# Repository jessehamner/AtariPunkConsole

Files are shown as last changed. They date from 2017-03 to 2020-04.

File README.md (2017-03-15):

# Atari Punk Console Implementation
##### *with modifications*

## What's In Here

- EAGLE CAD schematics 
- Detailed LaTeX documentation
- A few interesting EAGLE CAD scripts
    - at least one of which requires a script in another of my GitHub repositories
- a bill of materials for this implementation
- a python script that makes drawing 8-bit characters in EAGLE CAD pretty easy

## Where Things Are

- cad: EAGLE CAD files and the script to export images from the program
- docs: LaTeX documentation, images, and the bash script that uses ImageMagick to modify and improve the native png image exports
- graphics: EAGLE CAD scripts that draw old 8-bit characters as part of the silkscreen layers of the PCB; includes the source csv and the python script used to make the scripts

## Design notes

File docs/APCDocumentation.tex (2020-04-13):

\documentclass[12pt]{article}
\usepackage{tabularx}
\usepackage{xcolor}
\usepackage{graphicx}
\usepackage{rotating}
\usepackage{lscape}
%\usepackage{booktabs}
\usepackage{comment}
\usepackage{listings}
\usepackage{multicol,multirow}
\usepackage[top=1in, bottom=1in, left=1.25in, right=1.0in]{geometry}
\usepackage{hyperref}
\usepackage{longtable}
\usepackage{marvosym}
\usepackage{amsmath, amssymb}

% A few paragraph formatting parameters:
\parskip = 6pt
\parindent = 0.0in

% Set up the 'listings' package:
\lstdefinestyle{custombash}{
 language=bash, 
 columns=fullflexible, 
 breaklines=true, 
 basicstyle=\ttfamily\footnotesize, 
 numbers=left, 
 numbersep=5pt,
 commentstyle=\itshape\color{mygreen},
 keywordstyle=\bfseries\color{blue},
 numberstyle=\tiny\ttfamily\color{black}, 
 stringstyle=\color{brown},
 otherkeywords={DISPLAY, EXPORT, IMAGE, MONOCHROME, RIPUP, SET, COLOR_LAYER},
 frame=single]
}
\lstset{style=custombash}

% Set some parameters for the graphics:
\DeclareGraphicsExtensions{.pdf,.png,.jpg,.jpeg}
\graphicspath{{./}{../}{./images/}}

% The default "BLUE" for the web links isn't much to my liking. 
\definecolor{webblue}{rgb}{0,0,0.75}
\definecolor{mygreen}{rgb}{0,0.6,0}
\definecolor{gray60}{gray}{0.6}

% Some nice, well-worn shortcuts:
\newcommand{\+}{\item}		% easier than typing \item a lot
%\setlength{\parindent}{0in}	% easier than putting \noindent at every paragraph
\newcommand{\bi}{\begin{itemize}}
\newcommand{\ei}{\end{itemize}}
\newcommand{\bd}{\begin{description}}
\newcommand{\ed}{\end{description}}
\newcommand{\be}{\begin{enumerate}}
\newcommand{\ee}{\end{enumerate}}
\newcommand{\rr}{\raggedright}

% some table formatting shortcuts:
\renewcommand{\thefootnote}{\fnsymbol{footnote}}
\newcommand{\sep}{1mm}
\newcommand{\negsep}{-3mm}
\newcommand{\thisscale}{1.6}
\newcommand{\silkscale}{1.0}
\newcommand{\tabitem}{~~\llap{\textbullet}~~}

% Names of the layout graphics files, so nobody has to go looking for them
\newcommand{\colorimagename}{colorlayout.png}
\newcommand{\twolayermonochrome}{whiteboardlayout.png}
\newcommand{\topmonochrome}{toplayout.png}
\newcommand{\bottommonochrome}{bottomlayout.png}
\newcommand{\bottomsilk}{bottomsilk.png}
\newcommand{\topsilk}{topsilk.png}
\newcommand{\boarddimensions}{dimensions.png}

\newcommand{\revision}{1.2}

% A key for optional output, here, the ``how to make the images" section:
\newif\ifkey
\keyfalse
% Uncommenting \keytrue would set the ``key" variable to TRUE:
\keytrue

\begin{document}
\thispagestyle{empty}
\begin{center}
\begin{Huge}
Atari Punk Console\\
\end{Huge}
\bigskip
\begin{Large}
\ifkey
Assembly, Testing, and Designer's Guide\\
\else
Assembly and Testing Guide\\
\fi

\end{Large}
\bigskip
Board version \revision\\
Guide version 1.2\\
Jesse Hamner\\
\vspace{0.2in}

\end{center}

\tableofcontents

\vfill 

\begin{center}
\begin{tabular}{c p{1.0in} c}
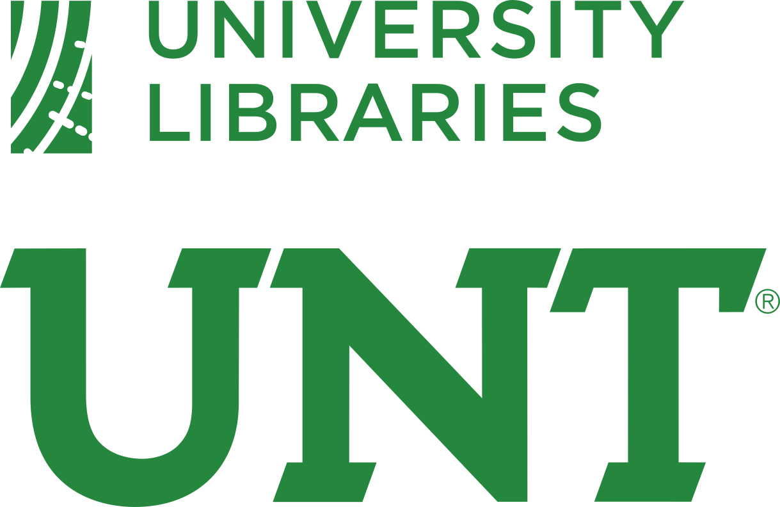
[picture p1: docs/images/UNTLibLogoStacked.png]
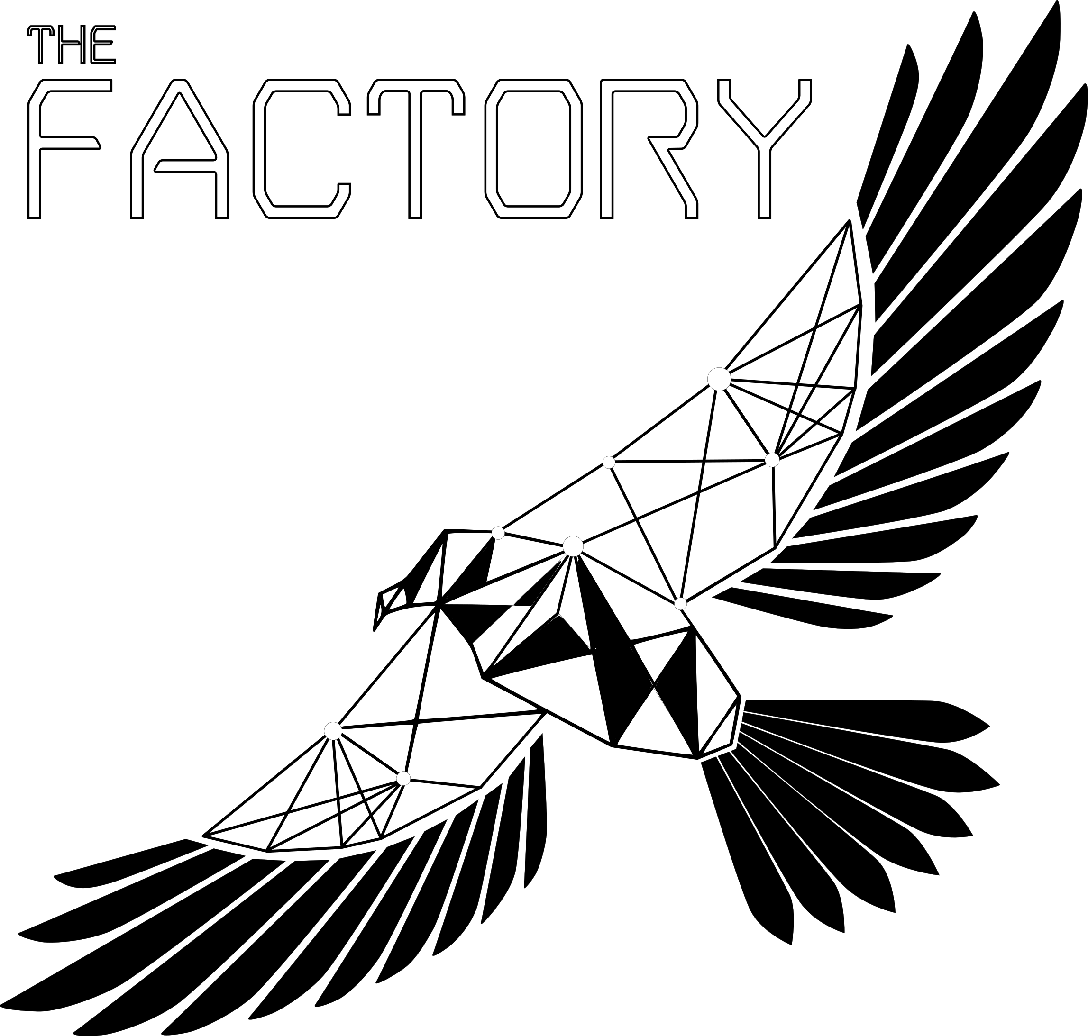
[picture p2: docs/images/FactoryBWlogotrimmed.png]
 & &  \\
\end{tabular}

\emph{Originally developed in collaboration with the UNT Libraries.}
\end{center}

\newpage

\section{Introduction}

In 1983, or some time before that, {\color{webblue}\href{http://www.forrestmims.org}{Forrest Mims III}}, a long-time participant in the electronics, hobbyist, and atmospheric science communities, designed the ``Stepped Tone Generator" using the wildly popular and hugely versatile {\color{webblue}\href{https://en.wikipedia.org/wiki/555_timer_IC}{555 timer integrated circuit}}. He published the design in a Radio Shack (Tandy Corp) book of projects\footnote{Mims, Forrest M., III. 1984. \emph{Engineers's Mini-notebook: 555 Timer IC Projects.} Fort Worth, Texas: Radio Shack.}, and then again in the 1992 \emph{Engineer's Mini-Notebook}\footnote{Mims, Forrest M., III. 1992. \emph{Engineer's Mini-Notebook}. 3\textsuperscript{rd} edition. Fort Worth, Texas: Radio Shack.}.

I was unable to find an example of this board that presented a simple design, an easy soldering task, but also an easy path to customization. People who are getting in to electronics, soldering, and/or ``making" may want a few easy ``wins" for their first few projects, and the ``{\color{webblue}\href{https://en.wikipedia.org/wiki/Atari_Punk_Console}{Atari Punk Console}}", as it has become known, is a simple circuit with a modest amount of expandability. 

I have re-implemented the design with the intent to provide a series of stepping stones from novice to an intermediate ``maker." Maker spaces like UNT's Factory provide a range of tools to end users, but like many tools, learning to use them can be a challenge. Here again, this design of the APC is up to the task. With easy alignment notches and a downloadable reference design for a 3D-printed case, users can learn to solder, solder the APC, and print a case for it, without facing serious hurdles. 

This project and its ancillary pieces allow novices to gain experience in several aspects of hobbyist making, while not facing the full force of electrical or industrial engineering. Put another way: one should not be required to learn typesetting in order to print a Microsoft Word document; neither should one be required to understand G-Code or STL files in order to produce a working and fun electronics project.

This guide provides graphical and instructional information about the assembly of this version of the ``Stepped Tone Generator". Please read this guide all the way through before beginning any work on the boards. 

%%%%%%%%%%%%%%%%%%%

\subsection*{Legal}

This document is intended to assist in the assembly of a circuit board project that synthesizes sound waves. This document comes with ABSOLUTELY NO WARRANTY. This document is released under the Creative Commons Attribution-ShareAlike  (CC BY-SA) license version 4.0. For more, see {\color{webblue}\href{https://creativecommons.org/licenses/}{creativecommons.org}}.
\begin{center}

\end{center}

%%%%%%%%%%%%%%%%%%%

\section{Best Practices}
\bi
\+ Use a wrist-strap ground during soldering; these components can be easily damaged by static electricity
\+ Use thin (perhaps 0.032-inch or 0.8mm) solder for through-hole components
\+ Use a good quality soldering iron
\+ Clean the tip often on the brass scrubber
\+ Re-tin the tip often
\+ Lifting PCB pads and traces is quite possible without much effort---watch the iron temperature, and don't apply heat for more than ten seconds per soldered pin 
\+ Don't buy or use low-quality solder, leaded or not; it gets gummy and is more or less impossible to remove without thermal damage to your components. Use name-brand solder, like {\color{webblue}\href{http://www.kester.com}{Kester}}
\+ Masking tape may be helpful to hold pin headers in place while soldering the underside
\+ Tweezers or small pliers are useful (but not necessary) for placement of the SMD component
\ei

\section{Useful Equipment For Testing}
\bi
\+ A 9V battery
\+ A 6V to 13.8V DC power source, capable of providing at least 300 milliamps of current
\+ A multimeter
\+ A stereo magnifier, an inspection loupe, and/or a USB microscope
\+ A third hand or PCB vise
\+ A set of headphones or a powered speaker
\ei

\section{Assembly Order}

\begin{itemize}
\+ Discrete resistors
\+ Diodes (note the orientation!)
\+ Disc capacitors
\+ Electrolytic (aluminum, polarized) capacitor(s)
\+ 2- and 3-pin headers
\+ LED (note the orientation!)
\+ 8-pin integrated circuit sockets (note the orientation!)
\+ DC power jack
\+ 9V battery cradle
\+ SMD headphone jack (see text)
\+ Variable resistors (potentiometers / rheostats)
\+ Switch
\end{itemize}

After the sockets are installed, consider the orientation of the 555 timers and press them completely into the sockets. It may be helpful to line up four pins on one side with the socket connector, insert them about 1mm, then gently press the opposite side pins inward until they can also be fit into the socket. 

When soldering the stereo jack, heat a large pad on the PCB and melt a little solder onto it. Align the jack and hold it in place (the tab will be on top of the now-tinned PCB pad) with pliers, tweezers, or whatever you have. Hold the soldering iron tip on top of the tab, or touching both the pad and the tab, and the heat will eventually melt the solder and bond the tab to the board. If you have correctly aligned the jack, the other tabs and pads will be easy to solder. If not, re-melt the solder until you can get the jack to align properly. It may be helpful to press down with the tweezers or pliers (even clamping the board and the jack together with them). You don't want the tab to ``float'' up on the solder blob. 

\section{Hardware Testing}

\bi
\+ Turn the switch to `off'
\+ Install a 9V battery in the battery carrier
\+ Using a multimeter, check the voltage at the output (left, on this board) terminal of diodes D1 and D2
\+ Turn the switch to `on' and check the power LED indicator
\+ If the LED does not illuminate, use a multimeter to confirm that there is at least 6 volts available at the LED positive terminal

\+ Set all the knobs to the middle
\+ plug in the headphones and check for sound

\ei

\begin{figure}[ht!]
\begin{center}
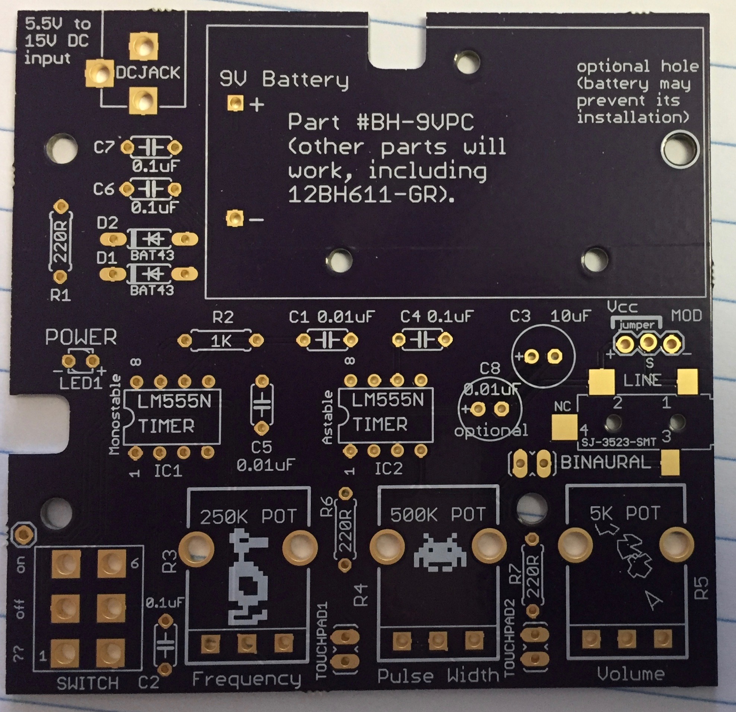
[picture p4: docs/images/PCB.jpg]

\end{center}
\caption{The bare printed circuit board for this project.}
\end{figure}

\begin{figure}[hb!]
\begin{center}
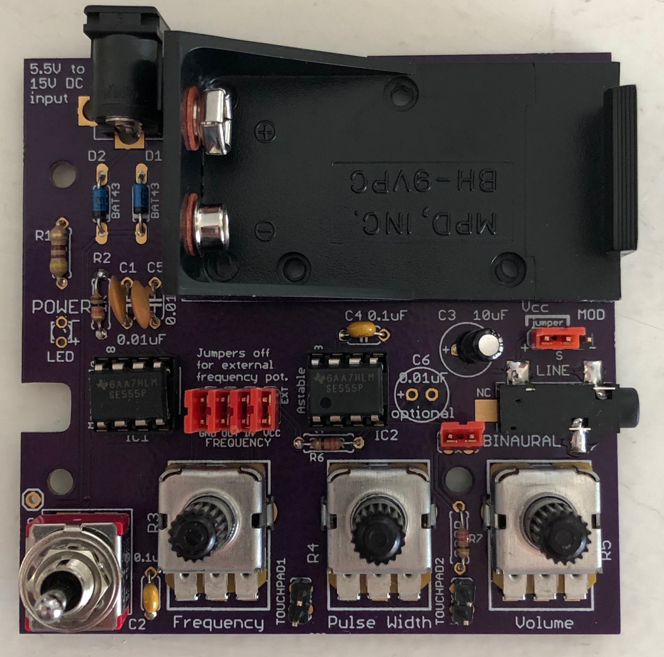
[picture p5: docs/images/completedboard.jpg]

\caption{A completed board, revision 1.2.}
\end{center}
\end{figure}

\clearpage

\section{Board Layout Images}

The next section includes images of the board design and layout for reference during the soldering and testing process. 

\begin{figure}[hb!]
\begin{center}

\end{center}

\caption{Color image unsuitable for monochrome printing. Both layers visible. Red traces are on the top layer, and blue traces are on the bottom layer. As would be expected if the board was transparent, all components on the bottom (although there are none for this board), and text, are reversed.}
\end{figure}

\begin{figure}
\begin{center}



\end{center}

\caption{Both layers visible. As would be expected if you could see through the board, elements on the bottom such as printed text are reversed. For this board, \emph{all components, headers, jacks, and connectors should be mounted on the top layer}, and soldered from the underside.}
\end{figure}

\newpage

\begin{figure}
\begin{center}

\end{center}
\caption{Top layer only. Some larger component outlines are shown in gray, as are two alignment notches in the board.}
\end{figure}

\begin{figure}
\begin{center}

\end{center}
\caption{Bottom layer only. \textbf{Important:} no jacks or headers should be soldered facing ``down." That is, \emph{only pins} should be visible when viewing the board from below. Note the alignment notches are reversed; this perspective is viewed from the bottom, not through the top of the board.}
\end{figure}

\newpage

\begin{figure}
\begin{center}
\begin{tabular}{cc}

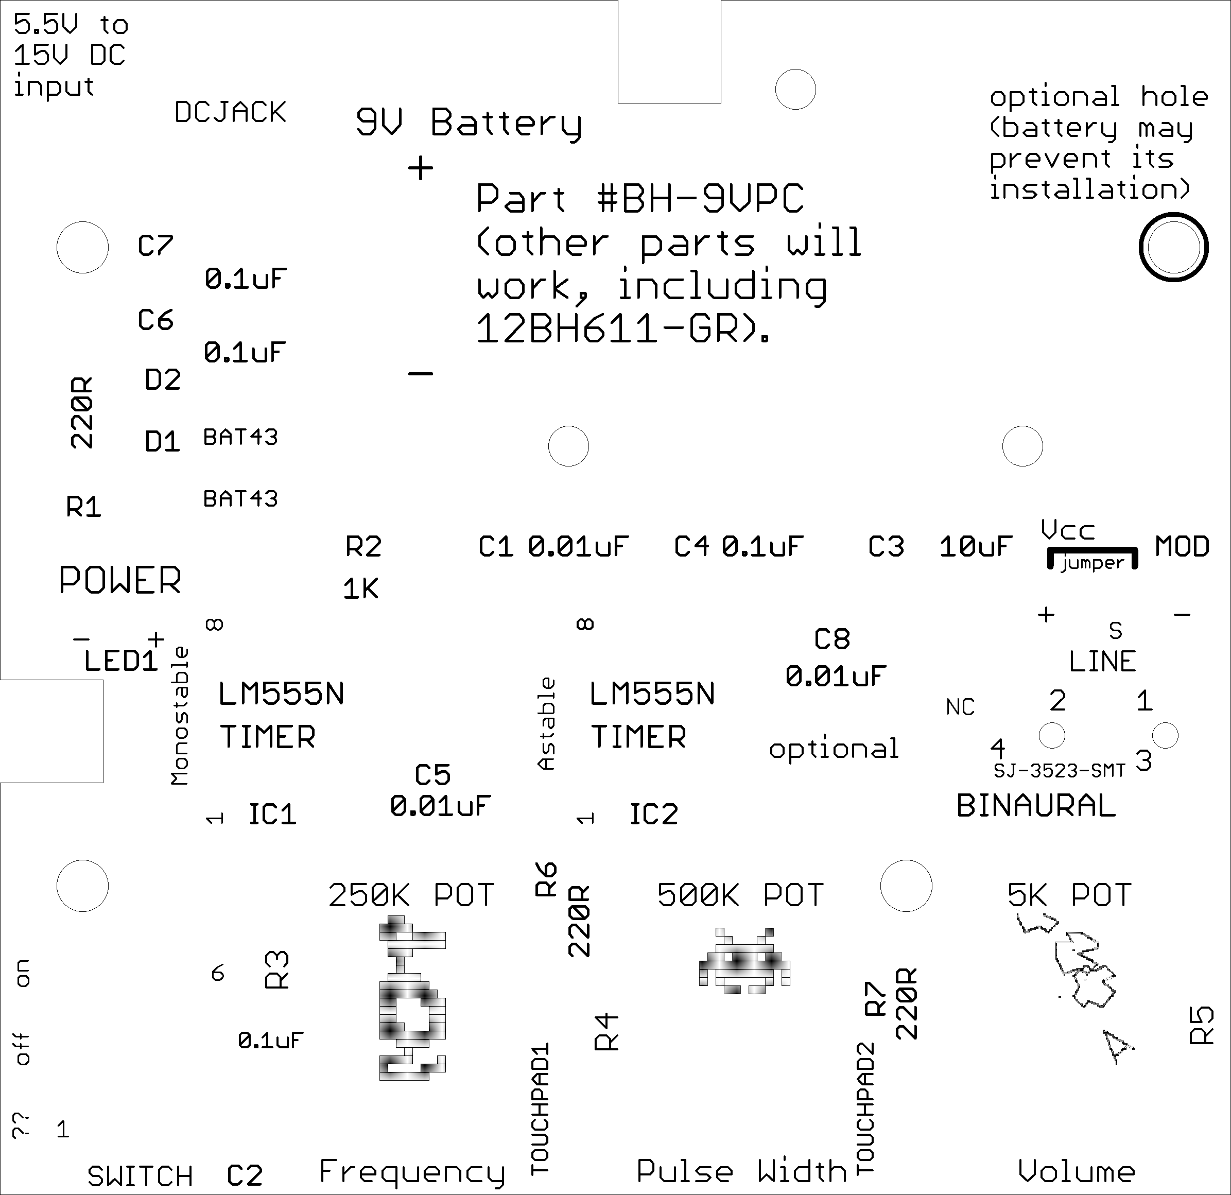
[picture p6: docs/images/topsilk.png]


&

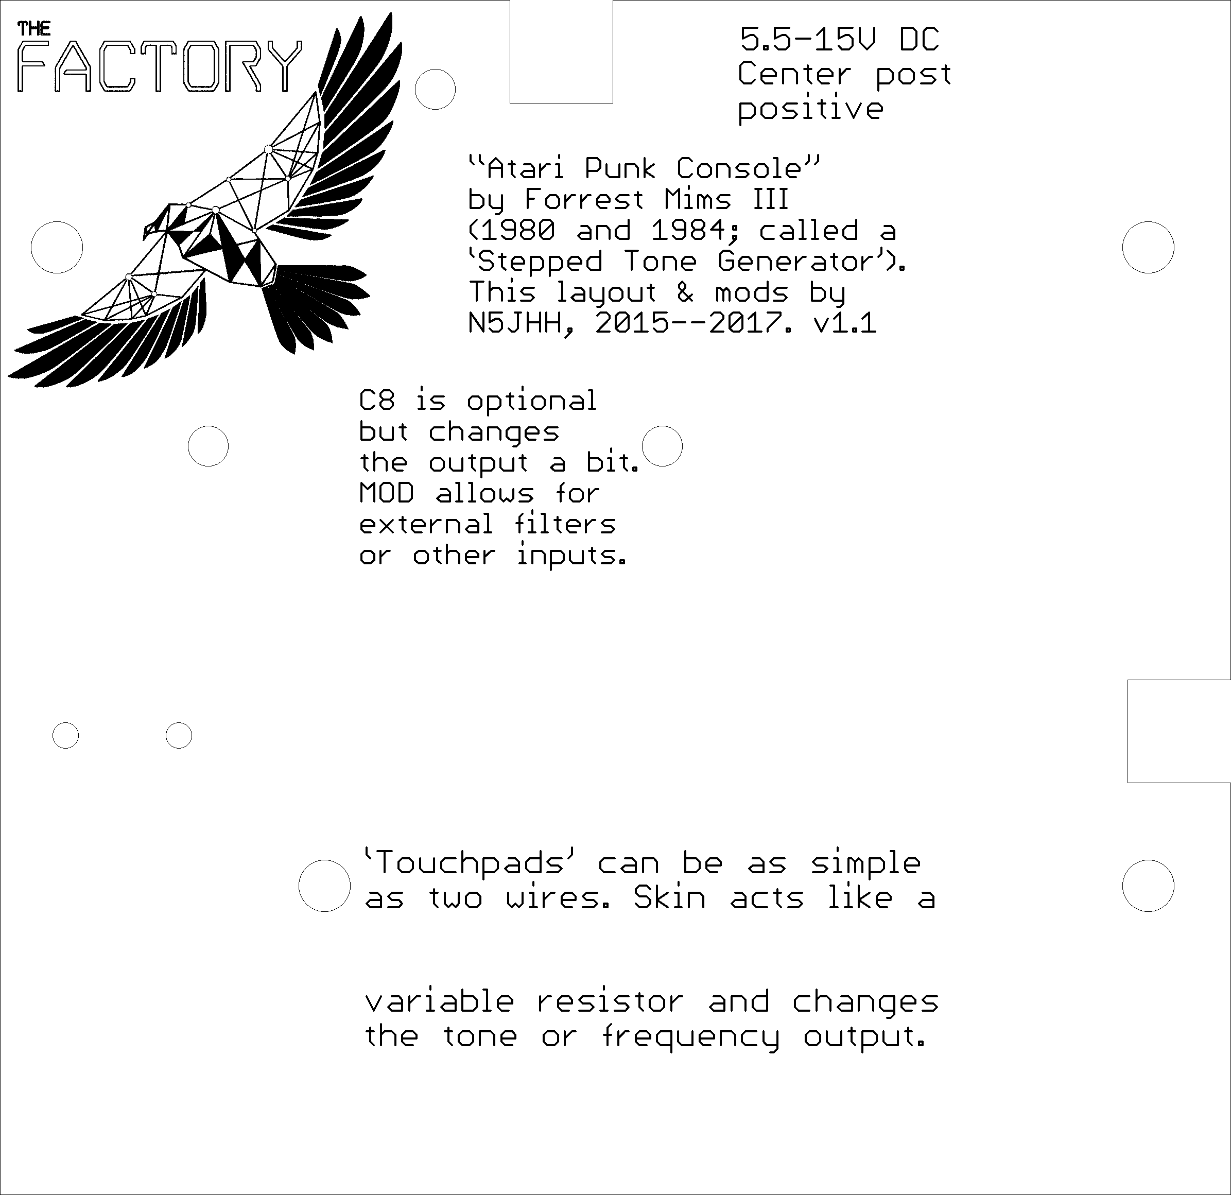
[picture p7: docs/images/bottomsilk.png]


\\

\end{tabular}

\end{center}
\caption{Silkscreens for top and bottom of the board. On the top silkscreen, note that the 8-bit Atari and Taito characters will be hidden under the rotary potentiometers once installed. From left to right: a dragon from the Atari 2600 \emph{Adventure} game; a Taito Space Invader; and a screen from \emph{Asteroids}. On the bottom silkscreen: note optional modification information and the Factory logo, copyright UNT Libraries.}
\end{figure}

\begin{figure}
\begin{center}

\end{center}
\caption{Board dimensions, should you want to design an enclosure for it. The three 2mm holes in the battery cradle could be attached to the underside of the enclosure with machine screws and nuts, but all fasteners must be flush with top surface of the cradle, meaning the underside of the enclosure would need recessed pockets for the nuts, or else rubberized feet that were taller than the portion of the fasteners that protrude through the bottom of the enclosure. It is also possible to create standoffs \emph{within} the case that provide underside clearance for fasteners such that the fasteners do not have exposed surfaces outside the case, at the slight expense of a taller overall case.}
\end{figure}

\clearpage 
\section{Device Schematic}

Although not required to successfully assemble and use the Stepped Tone Generator, some may find the schematic useful or interesting. There are also many schematics of similar implementations of Forrest Mims's work online. This implementation stays very close to the original, with a few small additions like the touchpad headers and the optional capacitors, that can be ignored if desired. I varied a few of the other components based on experience. To create this image, from the schematic pane, type (no quotes!)

\verb|EXPORT IMAGE $HOME/some/useful/path/APCschematic.png 800|

\bigskip

\begin{figure}[hb!]
\begin{center}
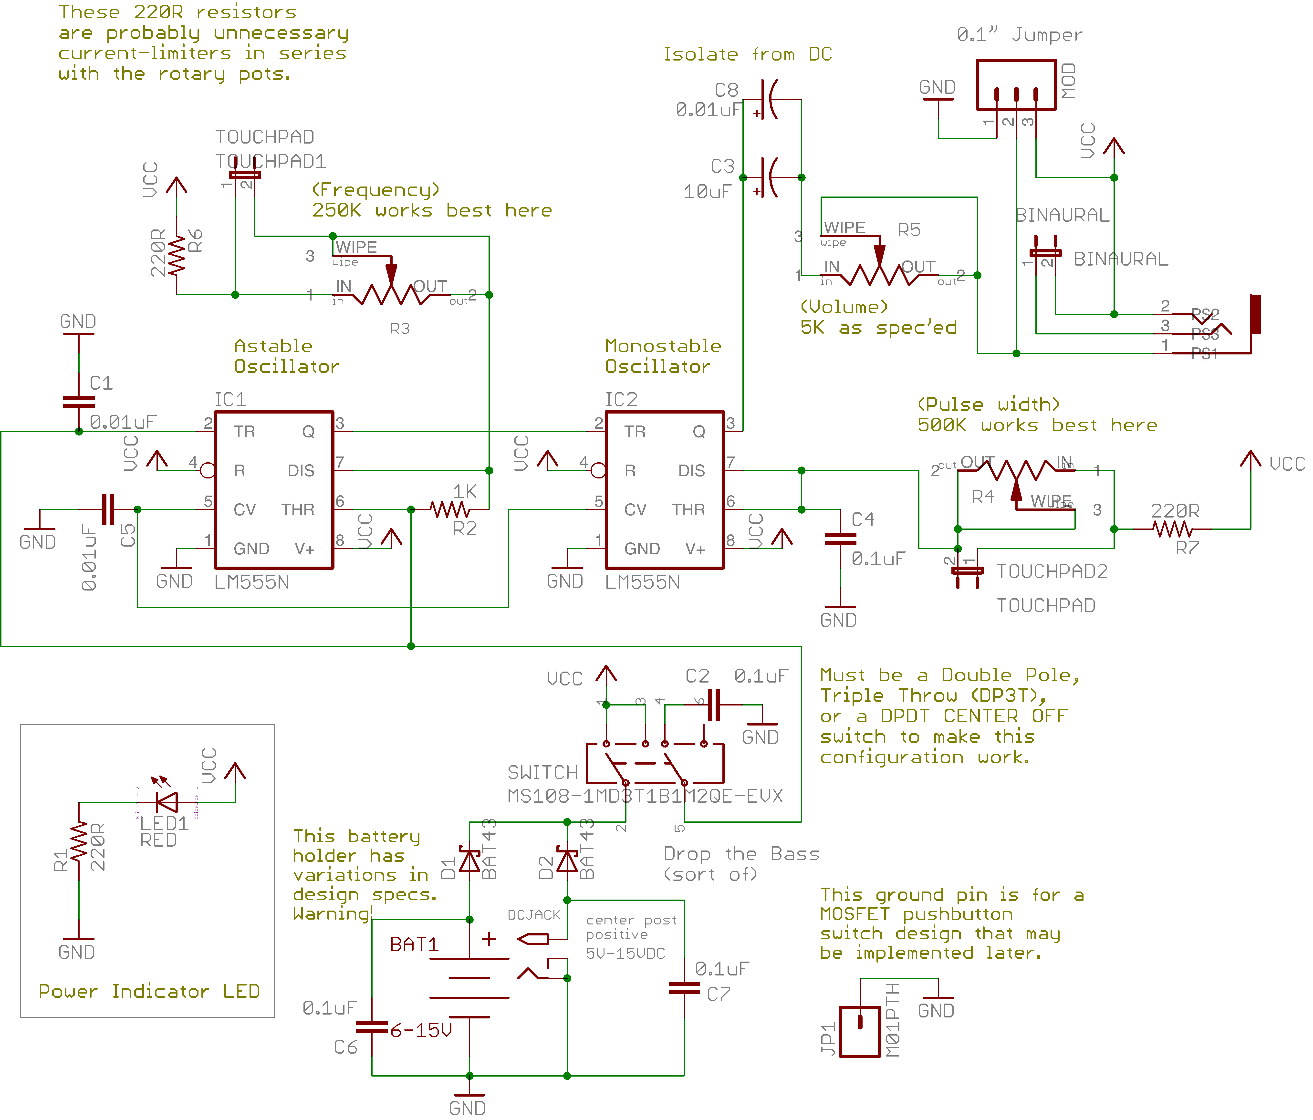
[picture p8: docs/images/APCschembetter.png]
 % original file: APCschematic.png
\end{center}
\caption{Schematic, with notes, as implemented in the board for this version.}
\end{figure}

%%%%%%%%%%%%%%%%%%%%%%%%%%%%%%%%%%%%%%%%%%%%%%%%%%%%%%%%%%%%%
%
% Optional section on making the images:
%
%%%%%%%%%%%%%%%%%%%%%%%%%%%%%%%%%%%%%%%%%%%%%%%%%%%%%%%%%%%%%

\ifkey 

\clearpage
\section{How To Make The Images In This Document}

This document includes images created from within Eagle CAD and using external programs. To show how it is done, and to provide any hints to those who would like to see how the documentation was made, I include the following mini-tutorial.

\subsection*{EagleCAD Schematic and Layout Images }

An EagleCAD script is provided in Figure \ref{fig:codelistexport} and in the GitHub repository. Run the script from within EagleCAD and the first set of images will appear. Basically, the script turns on the layers for each particular image, sets color or monochrome, sets the resolution to 600 DPI, and exports each resulting layer set to a PNG file. For instance, before making the \emph{top} layer, the script turns off the set of layers in EagleCAD that would make it hard to parse the top components -- i.e.~all of the ``bottom'' layers, like 16, 22, 24, 26, 28, 30, 32, 34, 36, 40, 42, 52, 122, 126, 128, and, as noted above, 200 (where the logo image silkscreen resides). To make an image of the underside, a similar operation is performed, blanking the ``top" layers. The script writes image files called:

\bigskip

\begin{tabular}{lll}
\tabitem \texttt{fullcolorboard.png} && \tabitem \texttt{boardlayout.png} \\[\sep]
\tabitem \texttt{boardtoplayout.png} && \tabitem \texttt{boardbottomlayout.png} \\[\sep]
\tabitem \texttt{boardbottomsilk.png} && \tabitem \texttt{boardtopsilk.png} \\[\sep]
\tabitem \texttt{boarddimensions.png} \\[\sep]
\end{tabular}

\begin{figure}
\vspace{-0.5in}
% Code listing:
\lstinputlisting[
 language=bash, 
 columns=fullflexible, 
 breaklines=true, 
 basicstyle=\ttfamily\footnotesize, 
 numbers=left, 
 numbersep=5pt,
 commentstyle=\color{mygreen},
 numberstyle=\tiny\ttfamily\color{black}, 
 frame=single]
 {./exportspecificlayers.scr}

\caption{The \texttt{EagleCAD} script to export images from EagleCAD.}
\label{fig:codelistexport}
\end{figure}

The script to appropriately convert the images is seen in Figure \ref{fig:codelistconvert}. The resulting files are called: 

\medskip

\begin{tabular}{lll}
\tabitem \texttt{\colorimagename} && \tabitem \texttt{\twolayermonochrome} \\[\sep]
\tabitem \texttt{\topmonochrome} && \tabitem \texttt{\bottommonochrome} \\[\sep]
\tabitem \texttt{\topsilk} && \tabitem \texttt{\bottomsilk} \\[\sep]
\tabitem \texttt{\boarddimensions} \\[\sep]
\end{tabular}
\medskip

\noindent This script was written for macOS but should run on any system with 
{\color{webblue}\href{https://en.wikipedia.org/wiki/Bash_%28Unix_shell%29}{\texttt{bash}}}
and {\color{webblue}\href{http://www.imagemagick.org/script/index.php}{ImageMagick}} installed.

\newpage

\begin{figure}[ht!]
\vspace{-0.5in}
% Code listing:
\lstinputlisting[
 language=bash, 
 columns=fullflexible, 
 breaklines=true, 
 basicstyle=\ttfamily\footnotesize, 
 numbers=left, 
 numbersep=5pt,
 commentstyle=\color{mygreen},
 numberstyle=\tiny\ttfamily\color{black}, 
 frame=single]
 {./images/imageprep.sh}
\caption{The \texttt{bash} script to correctly color the exported images from EagleCAD.}
\label{fig:codelistconvert}

\end{figure}

\clearpage
\newpage

\subsection*{8-bit Art in Eagle CAD}

The PCB also includes three pieces of art from the ancient era of video games. The Asteroids ship was converted using the \texttt{import-bmp.ulp} user language script that is included in Eagle CAD. The other two presented a fun challenge, which was to draw the 8-bit sprites using the Eagle CAD scripting language. It's pretty easy to draw squares and rectangles using the language, so I wrote a Python script that reads in a very simple csv file, composed of rows of comma-separated ``1'' or ``0'' cells. The Python script then writes out a nice (and easily scalable, if you check out the top of the script) Eagle CAD script that draws the figure in the layer you specify. It's much faster than drawing it yourself, and the CAM script runs much faster too, since the sprites are so simple.

\medskip

\begin{figure}[h!]

\begin{tabular}{ m{2.7in}  m{3.0in} }
\hline\\[\negsep]
\multicolumn{1}{c}{\textbf{CSV code}} & \multicolumn{1}{c}{\textbf{Image}} \\[\sep]
\hline
\bigskip
\lstinputlisting[
language=bash, 
 columns=fullflexible, 
 breaklines=true, 
 basicstyle=\ttfamily\footnotesize, 
 numbers=left, 
 numbersep=5pt,
 commentstyle=\color{black},
 numberstyle=\tiny\ttfamily\color{black}, 
 frame=none]
 {../graphics/pitfallharry.txt}

&

\fbox{
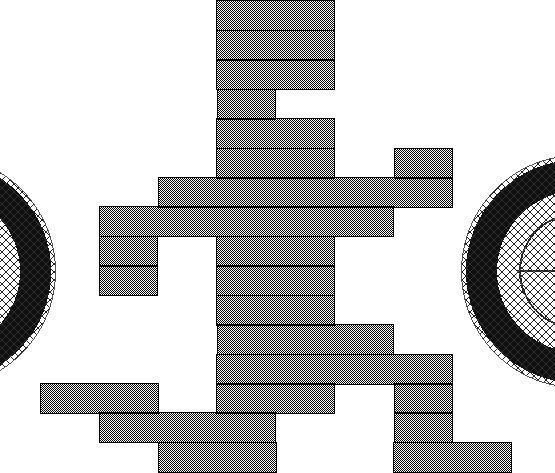
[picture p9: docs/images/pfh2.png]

}
\\
\hline
\end{tabular}

\caption{The comma-separated source text that \texttt{eagledraw.py} uses to write the script to draw Pitfall Harry, and the resulting image in Eagle CAD. Pitfall Harry is not displayed on the the board, but is used here as an example.}
\label{fig:pitfallharry}
\end{figure}

\clearpage
\newpage

\else
	\newpage
\fi

\begin{sidewaystable}
\section*{Bill of Materials}
\input{APC1BOM_export.tex}
\end{sidewaystable}

\clearpage

\section{Change Log}

\bd

\+[Revision \revision{}:] March 2017
\bi
\+ Fixed wiring on two potentiometers (I outsmarted myself and wired them in reverse, so the volume control, e.g., worked backwards)
\+ Re-routed traces to make the design friendly for desktop CNC mills
\+ Added two current-limiting resistors just to use best practices for the rotary potentiometers; the extra 220 Ohms doesn't affect the sound, but prevents runaway current should the wiper fail.
\ei

\+[1.0:] February 2017
\bi
\+ Initial release
\+ Changed switch to one in current production
\+ Re-routed and simplified some traces
\+ Moved and added labels
\+ Moved some discrete components
\ei

\+[0.4:] July 2016
\bi
\+ Shrunk the footprint of discrete resistors
\+ Renumbered a few components
\+ Altered the 9V cradle part's footprint to improve pin placement
\+ Changed a few labels
\ei

\+[0.3:] June 2016
\bi
\+ Changed switch
\+ Moved a few components for clearance
\ei

\+[0.2:] January 2016
\bi
\+ Revealed a problem with the switch layout
\ei

\+[0.1:] December 2015
\bi
\+ Corrected problems with component layout, clearance, and part names
\+ Added board cutouts to ensure it only fits in the enclosure in one specific orientation
\+ Shrunk discrete component pin spacings from 10mm to 7mm
\ei
\ed

\vfill

\begin{center}
\emph{This is the last page.}
\end{center}

\end{document}

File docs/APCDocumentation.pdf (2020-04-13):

# Atari Punk Console

## Assembly, Testing, and Designer’s Guide

Board version 1.2
Guide version 1.2
Jesse Hamner

## Contents

1 Introduction | 2
2 Best Practices | 3
3 Useful Equipment For Testing | 3
4 Assembly Order | 3
5 Hardware Testing | 4
6 Board Layout Images | 6
7 Device Schematic | 11
8 How To Make The Images In This Document | 12
9 Change Log | 17

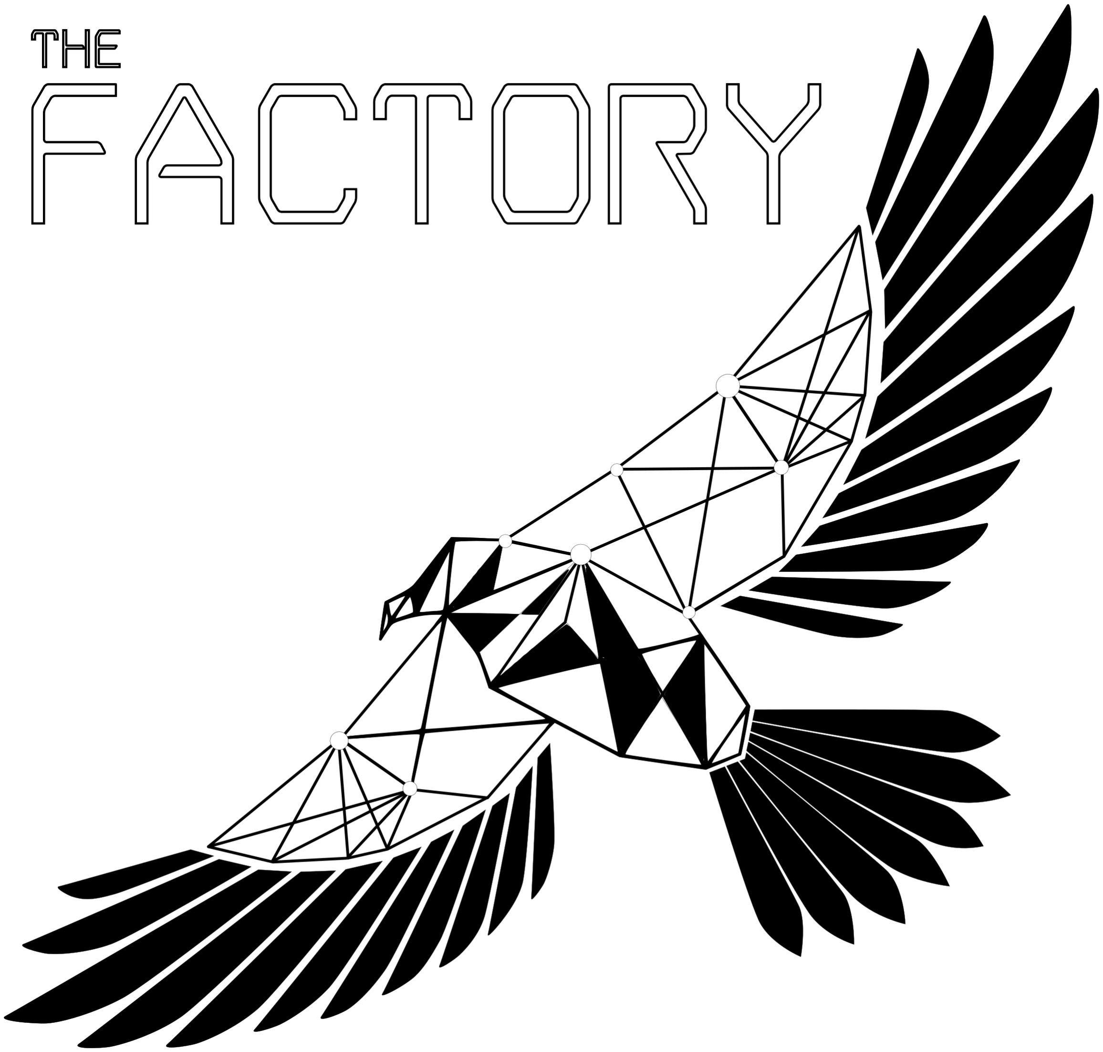
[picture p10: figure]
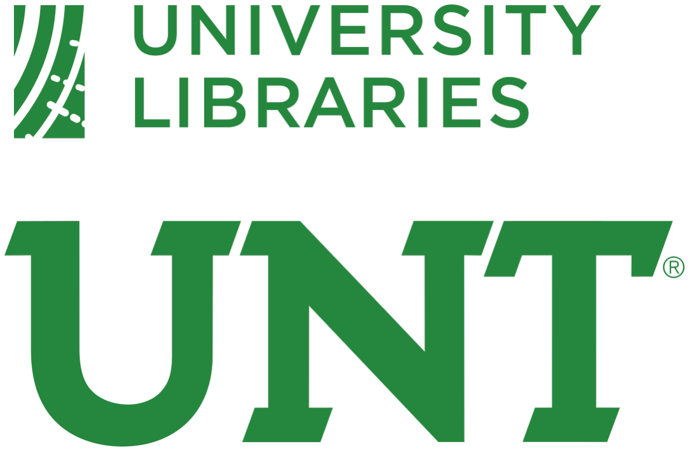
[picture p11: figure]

Originally developed in collaboration with the UNT Libraries.

## 1 Introduction

In 1983, or some time before that, Forrest Mims III, (http://www.forrestmims.org) a long-time participant in the electronics, hobbyist, and atmospheric science communities, designed the “Stepped Tone Generator” using the wildly popular and hugely versatile 555 timer integrated circuit. (https://en.wikipedia.org/wiki/555_timer_IC) He published the design in a Radio Shack (Tandy Corp) book of projects∗
, and then again
in the 1992 Engineer’s Mini-Notebook †

I was unable to find an example of this board that presented a simple design, an easy soldering task, but also an easy path to customization. People who are getting in to electronics, soldering, and/or “making” may want a few easy “wins” for their first few projects, and the “Atari Punk Console”, (https://en.wikipedia.org/wiki/Atari_Punk_Console) as it has become known, is a simple circuit with a modest amount of expandability.

I have re-implemented the design with the intent to provide a series of stepping stones from novice to an intermediate “maker.” Maker spaces like UNT’s Factory provide a range of tools to end users, but like many tools, learning to use them can be a challenge. Here again, this design of the APC is up to the task. With easy alignment notches and a downloadable reference design for a 3D-printed case, users can learn to solder, solder the APC, and print a case for it, without facing serious hurdles.

This project and its ancillary pieces allow novices to gain experience in several aspects of hobbyist making, while not facing the full force of electrical or industrial engineering. Put another way: one should not be required to learn typesetting in order to print a Microsoft Word document; neither should one be required to understand G-Code or STL files in order to produce a working and fun electronics project.

This guide provides graphical and instructional information about the assembly of this version of the “Stepped Tone Generator”. Please read this guide all the way through before beginning any work on the boards.

### Legal

This document is intended to assist in the assembly of a circuit board project that synthesizes sound waves. This document comes with ABSOLUTELY NO WARRANTY. This document is released under the Creative Commons Attribution-ShareAlike (CC BY-SA) license version 4.0. For more, see creativecommons.org. (https://creativecommons.org/licenses/)

∗Mims, Forrest M., III. 1984. Engineers’s Mini-notebook: 555 Timer IC Projects. Fort Worth, Texas: Radio Shack.
†Mims, Forrest M., III. 1992. Engineer’s Mini-Notebook. 3rd edition. Fort Worth, Texas: Radio Shack.

## 2 Best Practices

- Use a wrist-strap ground during soldering; these components can be easily damaged by static electricity
- Use thin (perhaps 0.032-inch or 0.8mm) solder for through-hole components
- Use a good quality soldering iron
- Clean the tip often on the brass scrubber
- Re-tin the tip often
- Lifting PCB pads and traces is quite possible without much effort—watch the iron temperature, and don’t apply heat for more than ten seconds per soldered pin
- Don’t buy or use low-quality solder, leaded or not; it gets gummy and is more or less impossible to remove without thermal damage to your components. Use name-brand solder, like Kester (http://www.kester.com)
- Masking tape may be helpful to hold pin headers in place while soldering the underside
- Tweezers or small pliers are useful (but not necessary) for placement of the SMD component

## 3 Useful Equipment For Testing

- A 9V battery
- A 6V to 13.8V DC power source, capable of providing at least 300 milliamps of current
- A multimeter
- A stereo magnifier, an inspection loupe, and/or a USB microscope
- A third hand or PCB vise
- A set of headphones or a powered speaker

## 4 Assembly Order

- Discrete resistors
- Diodes (note the orientation!)

- Disc capacitors
- Electrolytic (aluminum, polarized) capacitor(s)
- 2- and 3-pin headers
- LED (note the orientation!)
- 8-pin integrated circuit sockets (note the orientation!)
- DC power jack
- 9V battery cradle
- SMD headphone jack (see text)
- Variable resistors (potentiometers / rheostats)
- Switch

After the sockets are installed, consider the orientation of the 555 timers and press them completely into the sockets. It may be helpful to line up four pins on one side with the socket connector, insert them about 1mm, then gently press the opposite side pins inward until they can also be fit into the socket.

When soldering the stereo jack, heat a large pad on the PCB and melt a little solder onto it. Align the jack and hold it in place (the tab will be on top of the now-tinned PCB pad) with pliers, tweezers, or whatever you have. Hold the soldering iron tip on top of the tab, or touching both the pad and the tab, and the heat will eventually melt the solder and bond the tab to the board. If you have correctly aligned the jack, the other tabs and pads will be easy to solder. If not, re-melt the solder until you can get the jack to align properly. It may be helpful to press down with the tweezers or pliers (even clamping the board and the jack together with them). You don’t want the tab to “float” up on the solder blob.

## 5 Hardware Testing

- Turn the switch to ‘off’
- Install a 9V battery in the battery carrier
- Using a multimeter, check the voltage at the output (left, on this board) terminal of diodes D1 and D2
- Turn the switch to ‘on’ and check the power LED indicator
- If the LED does not illuminate, use a multimeter to confirm that there is at least 6 volts available at the LED positive terminal

- Set all the knobs to the middle
- plug in the headphones and check for sound


Figure 1: The bare printed circuit board for this project.


Figure 2: A completed board, revision 1.2.

## 6 Board Layout Images

The next section includes images of the board design and layout for reference during the soldering and testing process.

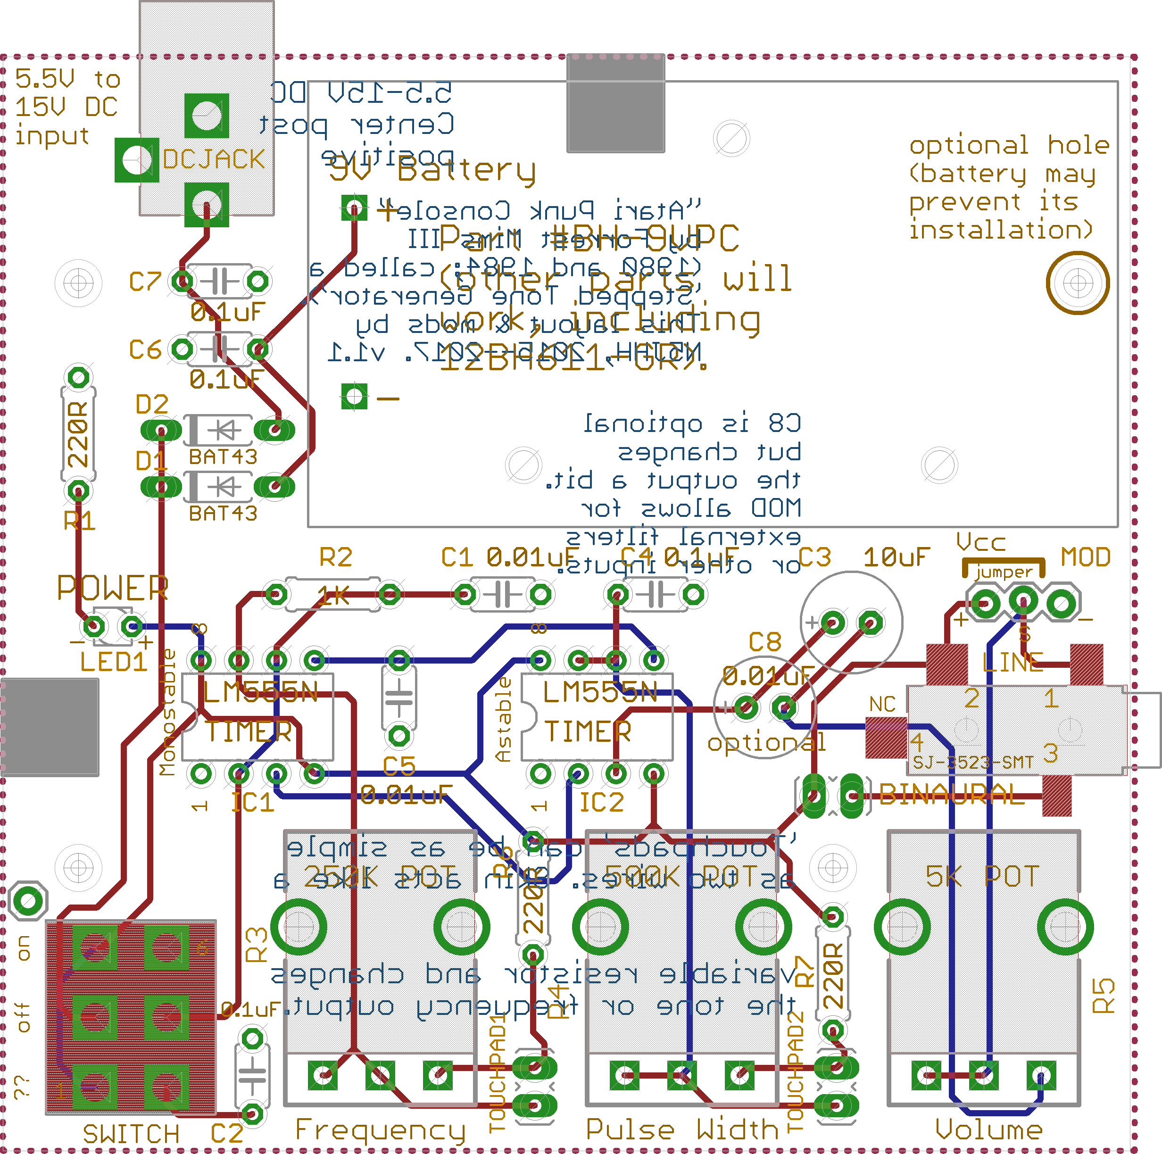
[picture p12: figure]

Figure 3: Color image unsuitable for monochrome printing. Both layers visible. Red traces are on the top layer, and blue traces are on the bottom layer. As would be expected if the board was transparent, all components on the bottom (although there are none for this board), and text, are reversed.

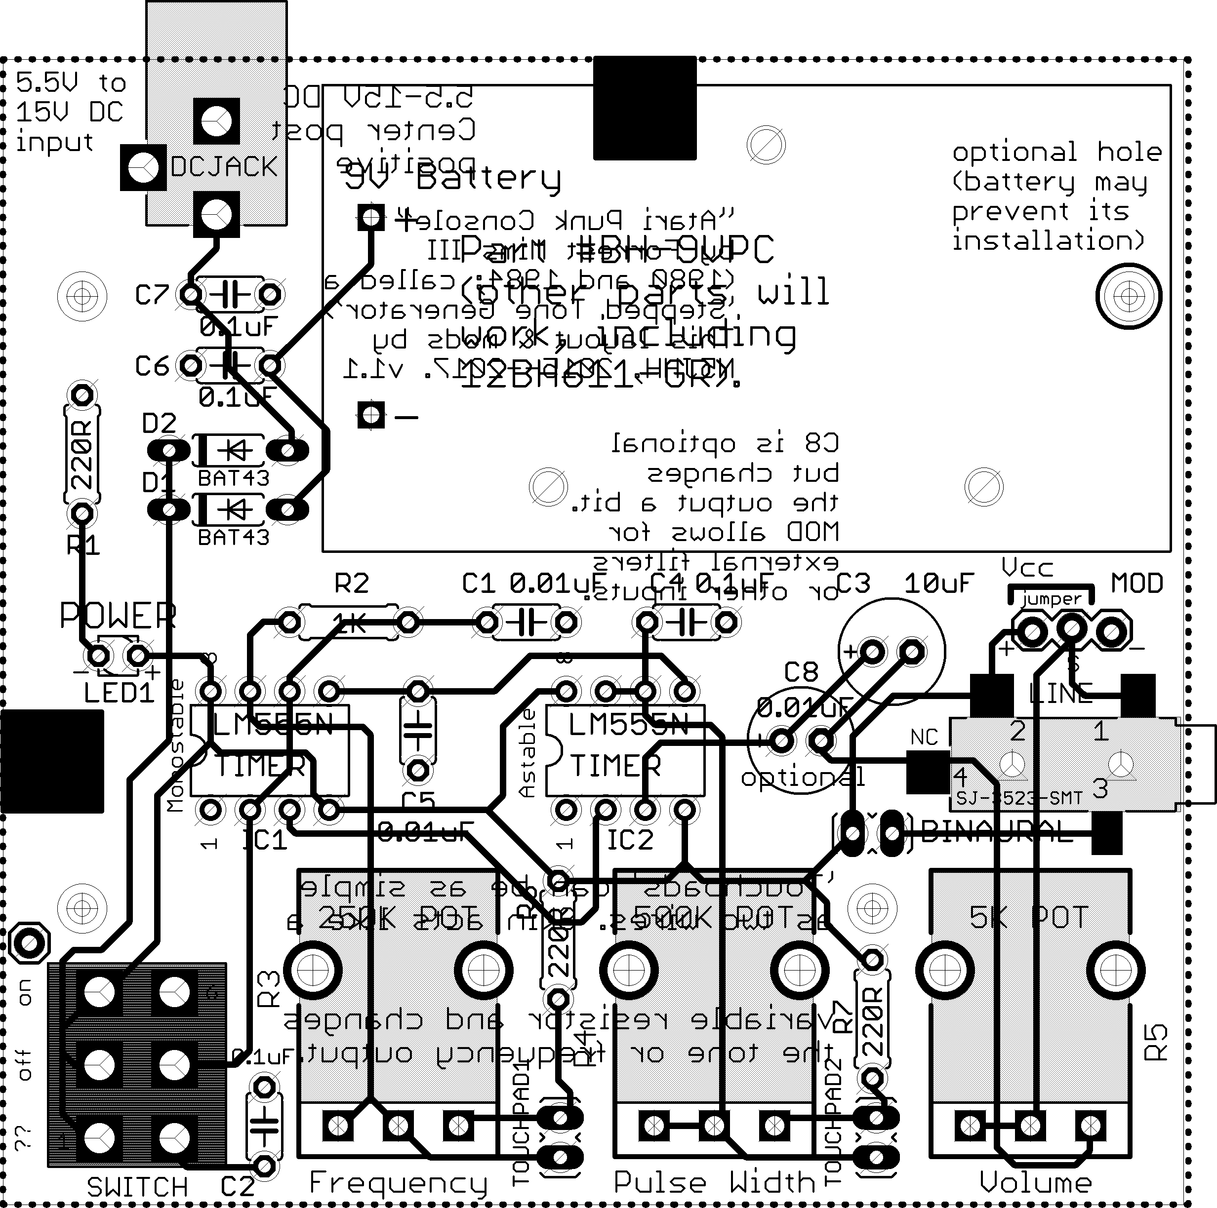
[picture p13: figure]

Figure 4: Both layers visible. As would be expected if you could see through the board, elements on the bottom such as printed text are reversed. For this board, all components, headers, jacks, and connectors should be mounted on the top layer, and soldered from the underside.

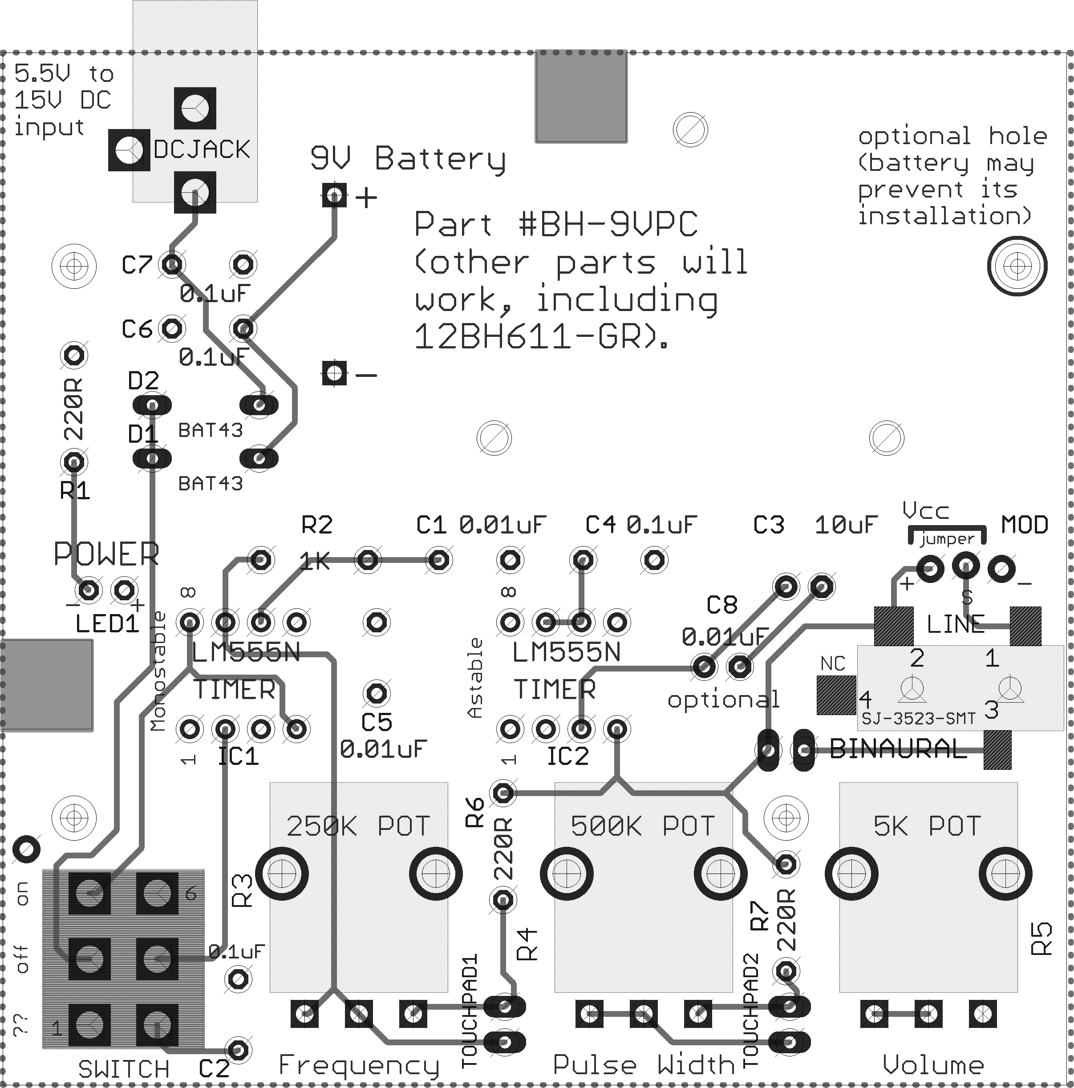
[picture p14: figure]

Figure 5: Top layer only. Some larger component outlines are shown in gray, as are two alignment notches in the board.

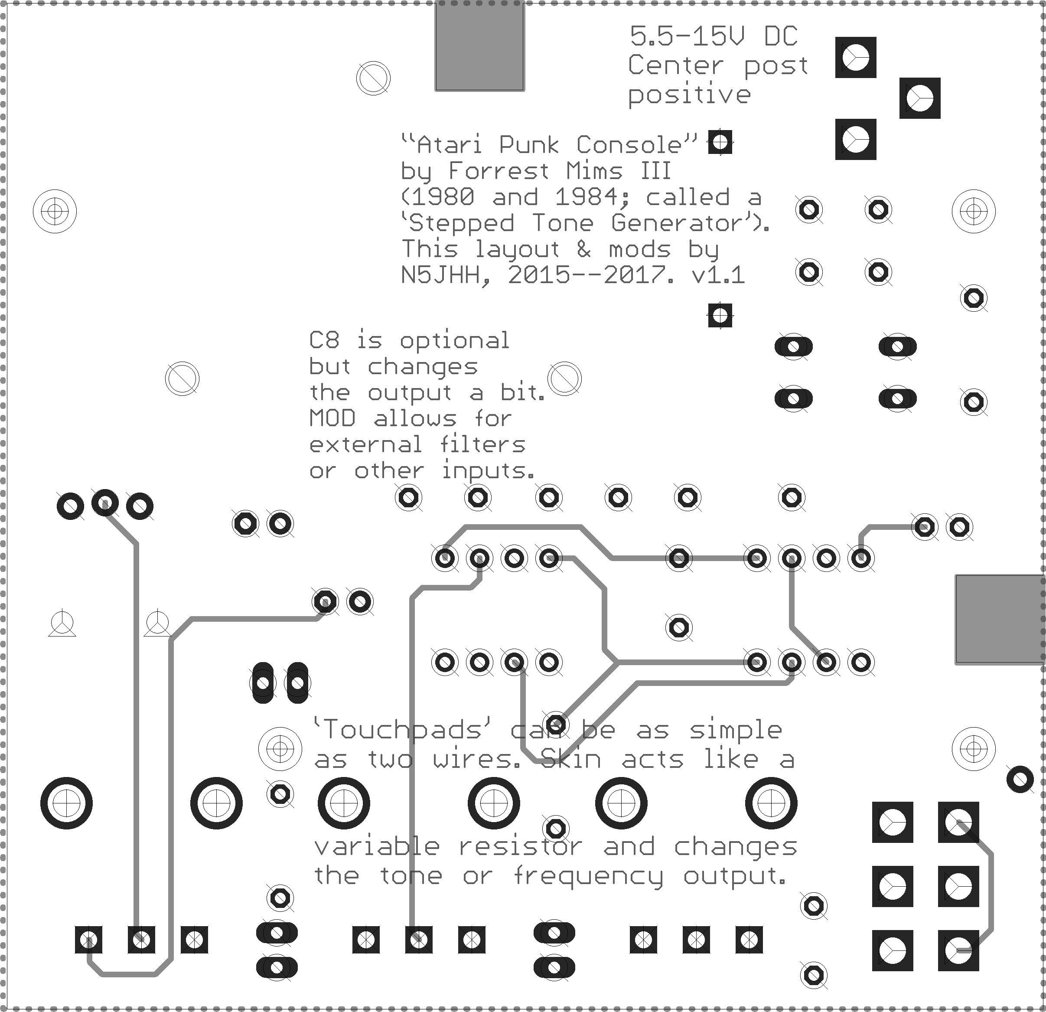
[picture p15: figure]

Figure 6: Bottom layer only. Important: no jacks or headers should be soldered facing “down.” That is, only pins should be visible when viewing the board from below. Note the alignment notches are reversed; this perspective is viewed from the bottom, not through the top of the board.


Figure 7: Silkscreens for top and bottom of the board. On the top silkscreen, note that the 8-bit Atari and Taito characters will be hidden under the rotary potentiometers once installed. From left to right: a dragon from the Atari 2600 Adventure game; a Taito Space Invader; and a screen from Asteroids. On the bottom silkscreen: note optional modification information and the Factory logo, copyright UNT Libraries.

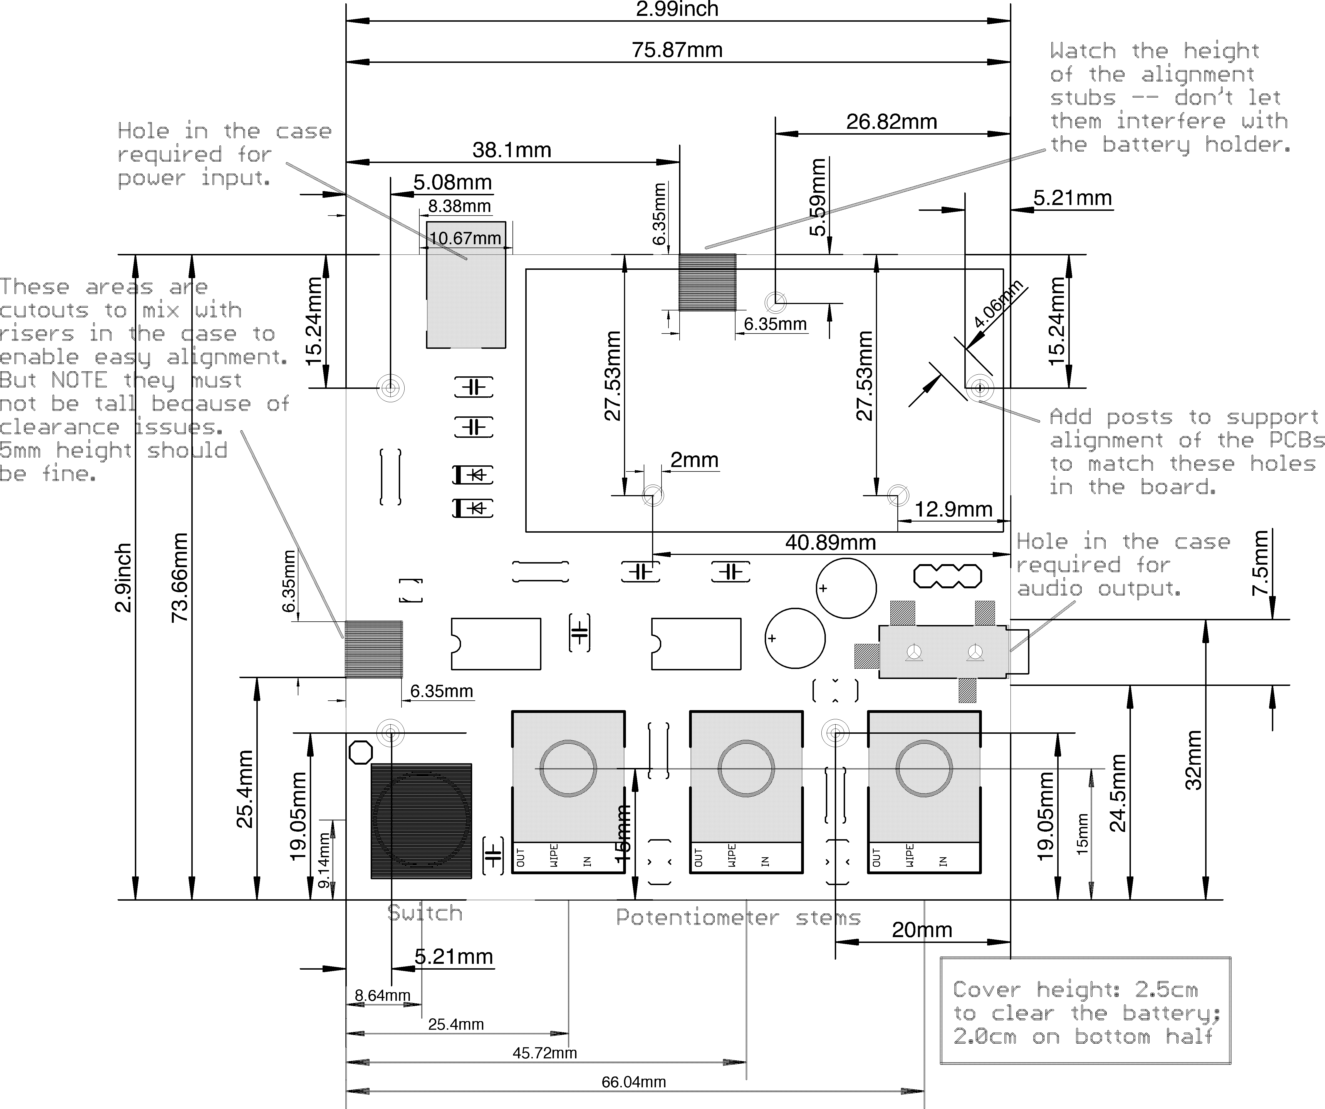
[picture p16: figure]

Figure 8: Board dimensions, should you want to design an enclosure for it. The three 2mm holes in the battery cradle could be attached to the underside of the enclosure with machine screws and nuts, but all fasteners must be flush with top surface of the cradle, meaning the underside of the enclosure would need recessed pockets for the nuts, or else rubberized feet that were taller than the portion of the fasteners that protrude through the bottom of the enclosure. It is also possible to create standoffs within the case that provide underside clearance for fasteners such that the fasteners do not have exposed surfaces outside the case, at the slight expense of a taller overall case.

## 7 Device Schematic

Although not required to successfully assemble and use the Stepped Tone Generator, some may find the schematic useful or interesting. There are also many schematics of similar implementations of Forrest Mims’s work online. This implementation stays very close to the original, with a few small additions like the touchpad headers and the optional capacitors, that can be ignored if desired. I varied a few of the other components based on experience. To create this image, from the schematic pane, type (no quotes!)

EXPORT IMAGE $HOME/some/useful/path/APCschematic.png 800


Figure 9: Schematic, with notes, as implemented in the board for this version.

## 8 How To Make The Images In This Document

This document includes images created from within Eagle CAD and using external pro-grams. To show how it is done, and to provide any hints to those who would like to see how the documentation was made, I include the following mini-tutorial.

### EagleCAD Schematic and Layout Images

An EagleCAD script is provided in Figure 10 and in the GitHub repository. Run the script from within EagleCAD and the first set of images will appear. Basically, the script turns on the layers for each particular image, sets color or monochrome, sets the resolution to 600 DPI, and exports each resulting layer set to a PNG file. For instance, before making the top layer, the script turns off the set of layers in EagleCAD that would make it hard to parse the top components – i.e. all of the “bottom” layers, like 16, 22, 24, 26, 28, 30, 32, 34, 36, 40, 42, 52, 122, 126, 128, and, as noted above, 200 (where the logo image silkscreen resides). To make an image of the underside, a similar operation is performed, blanking the “top” layers. The script writes image files called:

- fullcolorboard.png | • boardlayout.png
- boardtoplayout.png | • boardbottomlayout.png
- boardbottomsilk.png | • boardtopsilk.png
- boarddimensions.png

The script to appropriately convert the images is seen in Figure 11. The resulting files are called:

- colorlayout.png | • whiteboardlayout.png
- toplayout.png | • bottomlayout.png
- topsilk.png | • bottomsilk.png
- dimensions.png

This script was written for macOS but should run on any system with bash (https://en.wikipedia.org/wiki/Bash_%28Unix_shell%29) and ImageMagick (http://www.imagemagick.org/script/index.php) installed.

1 | # An EagleCAD script to export four versions of a circuit board:
2 | # 2 layers in color; and B/W, two layers, top layer, bottom layer,
3 | # and silkscreen layers for each top and bottom.

4
5 # Jesse Hamner, July 2016

6
7 | # Turn on the layers we want to see (note the RIPUP; won’t render polygons)
8 | # 200bmp is off, because it obscures the bottom layer

9
10 | SET COLOR_LAYER fp3 7;
11 | RIPUP @ GND;
12 | DISPLAY NONE TOP BOTTOM PADS VIAS DIMENSION UNROUTED TPLACE BPLACE TNAMES BNAMES
| TCREAM BCREAM TKEEPOUT BKEEPOUT TRESTRICT BRESTRICT VRESTRICT DRILLS HOLES _tsilk
| _bsilk _tNames _bNames _tValues _bValues Drill_legend _bDocu fp3

13
14 | # Export the color image:
15 | EXPORT IMAGE $HOME/AtariPunkConsole/docs/images/fullcolorboard.png 800;

16
17 | # Monochrome image, both layers:
18 | EXPORT IMAGE $HOME/AtariPunkConsole/docs/images/boardlayout.png MONOCHROME 800;

19
20 | # Turn on the top layers only:
21 | SET COLOR_LAYER fp3 8;
22 | DISPLAY NONE TOP PADS VIAS DIMENSION TNAMES TCREAM DRILLS HOLES _tsilk _tNames
| _tValues Drill_legend TKEEPOUT TRESTRICT fp3

23
24 | # Monochrome image, top layer:
25 | EXPORT IMAGE $HOME/AtariPunkConsole/docs/images/boardtoplayout.png 800;

26
27 | # Turn on the bottom layers only:
28 | DISPLAY NONE BOTTOM PADS VIAS DIMENSION BNAMES BCREAM DRILLS HOLES _bsilk _bNames
| _bValues Drill_legend _bDocu BKEEPOUT BRESTRICT fp3

29
30 | # Monochrome image, bottom layer:
31 | EXPORT IMAGE $HOME/AtariPunkConsole/docs/images/boardbottomlayout.png 800;

32
33 | # Top silk:
34 | DISPLAY NONE DIMENSION _tsilk TNAMES 201bmp 202bmp 203bmp
35 | EXPORT IMAGE $HOME/AtariPunkConsole/docs/images/boardtopsilk.png MONOCHROME 800;

36
37 | # Bottom silk:
38 | DISPLAY NONE 200bmp DIMENSION _bsilk _bnames BNAMES
39 | EXPORT IMAGE $HOME/AtariPunkConsole/docs/images/boardbottomsilk.png MONOCHROME 800;

40
41 | # Dimensions for the case:
42 | DISPLAY NONE DIMENSION tPlace tCream tKeepout tRestrict Holes Milling Document
| Reference Notes
43 | EXPORT IMAGE $HOME/AtariPunkConsole/docs/images/boarddimensions.png MONOCHROME 800;

44
45 | # Turn all the layers back on, including 200bmp this time
46 | DISPLAY NONE TOP BOTTOM PADS VIAS UNROUTED TPLACE tDocu bDocu BPLACE TORIGINS BORIGINS
| TNAMES BNAMES TVALUES BVALUES TSTOP BSTOP TCREAM BCREAM TKEEPOUT BKEEPOUT
| TRESTRICT BRESTRICT VRESTRICT DRILLS HOLES _tsilk _bsilk _tNames _bNames _tValues
| _bValues _bDocu 200bmp DIMENSION

47
48 # <EOF>

Figure 10: The EagleCAD script to export images from EagleCAD.

#!/bin/bash

# Program to convert image output from EagleCAD to a print-friendly format. # Note this script requires ImageMagick to be installed.

# Jesse Hamner, July 2016

function trimnegate {
echo "Converting $1.png to $2.png:" convert "$1.png" -trim -negate $3 "$2.png" rm "$1.png"

}

# To create the full color image but keep the color information: IMG="fullcolorboard"

DEST="colorlayout"
echo "Converting ${IMG}.png to ${DEST}.png:"
convert ${IMG}.png -transparent black ${IMG}NB.png
convert ${IMG}NB.png -alpha off -trim -fuzz 10% -fill white -opaque black \ ${DEST}.png

# To invert the colors of the multi-layer monochrome image: IMG="boardlayout"

trimnegate "${IMG}" "white${IMG}"

# To invert the colors of the top/bottom layer and convert to grayscale: DEST="toplayout"

IMG="board${DEST}"
trimnegate "${IMG}" "${DEST}" "-colorspace gray -gamma 0.3 " # improve contrast

DEST="bottomlayout"
IMG="board${DEST}"
trimnegate "${IMG}" "${DEST}" "-colorspace gray -flop -gamma 0.3 " # and reverse image

# Do the silkscreen layers :

DEST="topsilk"
IMG="board${DEST}"
trimnegate "${IMG}" "${DEST}"

DEST="bottomsilk"
IMG="board${DEST}"
trimnegate "${IMG}" "${DEST}" "-flop" # reverse the bottom image

DEST="dimensions"
IMG="board${DEST}"
trimnegate "${IMG}" "${DEST}" "-colorspace gray -gamma 0.9 " # improve contrast

convert APCschematic.png -gamma 0.95 -brightness-contrast -20x60 APCschembetter.png

# Clean up:

for F in fullcolorboardNB fullcolorboard

do
if [ -e "${F}.png" ]; then
rm ${F}.png

fi
done
# <EOF>

Figure 11: The bash script to correctly color the exported images from EagleCAD.

### 8-bit Art in Eagle CAD

The PCB also includes three pieces of art from the ancient era of video games. The Asteroids ship was converted using the import-bmp.ulp user language script that is included in Eagle CAD. The other two presented a fun challenge, which was to draw the 8-bit sprites using the Eagle CAD scripting language. It’s pretty easy to draw squares and rectangles using the language, so I wrote a Python script that reads in a very simple csv file, composed of rows of comma-separated “1” or “0” cells. The Python script then writes out a nice (and easily scalable, if you check out the top of the script) Eagle CAD script that draws the figure in the layer you specify. It’s much faster than drawing it yourself, and the CAM script runs much faster too, since the sprites are so simple.

CSV code | Image

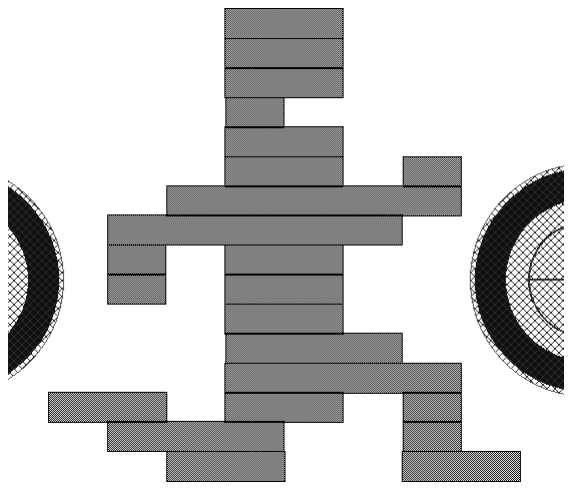
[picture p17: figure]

1 0,0,0,0,0,0,1,1,1,1,0,0,0,0,0,0 2 0,0,0,0,0,0,1,1,1,1,0,0,0,0,0,0 3 0,0,0,0,0,0,1,1,1,1,0,0,0,0,0,0 4 0,0,0,0,0,0,1,1,0,0,0,0,0,0,0,0 5 0,0,0,0,0,0,1,1,1,1,0,0,0,0,0,0 6 0,0,0,0,0,0,1,1,1,1,0,0,1,1,0,0 7 0,0,0,0,1,1,1,1,1,1,1,1,1,1,0,0 8 0,0,1,1,1,1,1,1,1,1,1,1,0,0,0,0 9 0,0,1,1,0,0,1,1,1,1,0,0,0,0,0,0 10 0,0,1,1,0,0,1,1,1,1,0,0,0,0,0,0 11 0,0,0,0,0,0,1,1,1,1,0,0,0,0,0,0 12 0,0,0,0,0,0,1,1,1,1,1,1,0,0,0,0 13 0,0,0,0,0,0,1,1,1,1,1,1,1,1,0,0 14 1,1,1,1,0,0,1,1,1,1,0,0,1,1,0,0 15 0,0,1,1,1,1,1,1,0,0,0,0,1,1,0,0 16 0,0,0,0,1,1,1,1,0,0,0,0,1,1,1,1

Figure 12: The comma-separated source text that eagledraw.py uses to write the script to draw Pitfall Harry, and the resulting image in Eagle CAD. Pitfall Harry is not displayed on the the board, but is used here as an example.

## Bill of Materials

### Part Value Package Description Digi-Key Part

BAT1 6-15V BH9VPC Battery holder is BH-9VPC, but part

12BH611-GR is substitutable.

BH9V-PC-ND

BINAURAL 0.1" header JP1 jumper for two-channel audio output. S1011EC-40-ND
shunt 0.1" shunt shunt to bridge jumpers 2-881545-2-ND

C1,C5,C8 0.01µF C050-024X044 ceramic disc capacitor BC1078CT-ND
C2,C4,C6,C7 0.1µF C050-024X044 ceramic disc capacitor 399-9870-1-ND
C3 10µF E2,5-7 polarized capacitor P15799CT-ND

D1,D2 BAT43 DO35-7 Schottky diode, 0.45V fwd, 30V, 200mA 497-2492-1-ND
DCJACK PJ102A PJ-102A DC jack, 2.0mm center pin, 5.5mm plug CP-102A-ND

IC1, IC2 LM555N DIL08 555 Timer IC 296-9684-5-ND
SOCKET1,2 A 08-LC-TT DIL08 8 pin DIP IC socket AE9986-ND

JP1 M01PTH 1X01 1-pin header to ground S1011EC-40-ND
LED1 859-LTL2R3KRD-EM 5mm, 2.54mm spacing red LED, 2mA, 1.8V fwd 160-1853-ND

LINE SJ-3523-SMT SJ352 Audio Jack CUI inc Stereo Audio SMT jack, 3.5mm CP-3523SJCT-ND

MOD 0.1" header 1X03 3 pin header for mods (see above)

R1,R6,R7 220R 0207/7 through-hole resistor CF18JT220RCT-ND

R2 1K 0207/7 through-hole resistor S1KQCT-ND
R3 250K CTS UM296RE pot Frequency potentiometer CT2269-ND
R4 500K CTS UM296RE pot Pulse-width potentiometer CT2270-ND

R5 5K CTS UM296RE pot Volume potentiometer CT2264-ND

SWITCH 108-1MD3T1B1M2QE-EVX — Mountain Switch DPDT center-off switch (only at Mouser)

TOUCHPAD1,2 0.1" header JP1, JP2 optional touch pad connection (see above)

## 9 Change Log

Revision 1.2: March 2017

- Fixed wiring on two potentiometers (I outsmarted myself and wired them in reverse, so the volume control, e.g., worked backwards)
- Re-routed traces to make the design friendly for desktop CNC mills
- Added two current-limiting resistors just to use best practices for the rotary potentiometers; the extra 220 Ohms doesn’t affect the sound, but prevents runaway current should the wiper fail.

1.0: February 2017

- Initial release
- Changed switch to one in current production
- Re-routed and simplified some traces
- Moved and added labels
- Moved some discrete components

0.4: July 2016

- Shrunk the footprint of discrete resistors
- Renumbered a few components
- Altered the 9V cradle part’s footprint to improve pin placement
- Changed a few labels

0.3: June 2016

- Changed switch
- Moved a few components for clearance

0.2: January 2016

- Revealed a problem with the switch layout

0.1: December 2015

- Corrected problems with component layout, clearance, and part names
- Added board cutouts to ensure it only fits in the enclosure in one specific orientation
- Shrunk discrete component pin spacings from 10mm to 7mm

This is the last page.

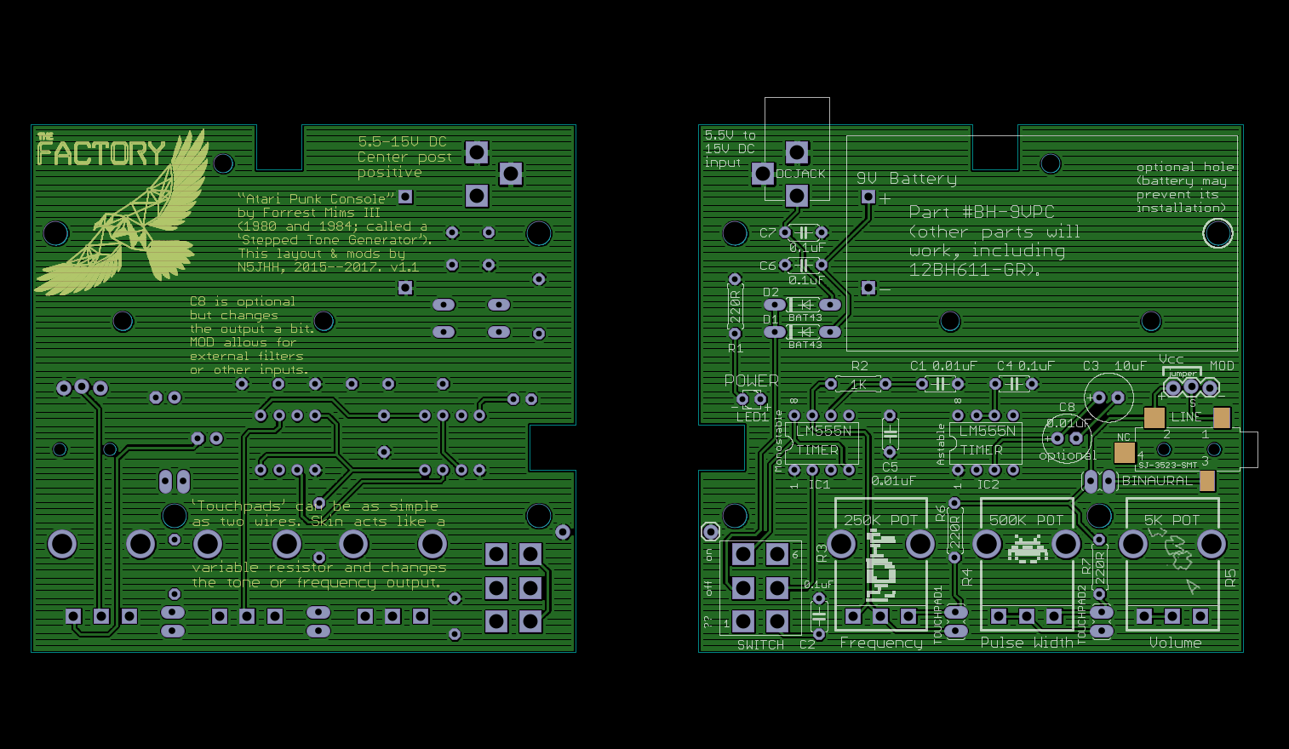
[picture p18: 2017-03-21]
docs/images/gerbvrender.png

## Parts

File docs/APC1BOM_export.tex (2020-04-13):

\begin{footnotesize}
\begin{tabular}{l l p{1.7in}  p{2.6in} l }

\large{\textbf{Part}} &  
\large{\textbf{Value}} &  
\large{\textbf{Package}} &  
\large{\textbf{Description}} & 
\large{\textbf{Digi-Key Part}} 
\\[\sep]
\hline\\[\negsep]

$\square$ BAT1      & 6-15V       & BH9VPC          & Battery holder is BH-9VPC, but part 12BH611-GR is substitutable. & BH9V-PC-ND \\
$\square$ BINAURAL  & 0.1\texttt{"} header & JP1    & jumper for two-channel audio output. & S1011EC-40-ND \\
$\square$ shunt     & 0.1\texttt{"} shunt &         & shunt to bridge jumpers & 2-881545-2-ND \\
$\square$ C1,C5,C8  & 0.01$\mu$F  & C050-024X044    & ceramic disc capacitor  & BC1078CT-ND  \\
$\square$ C2,C4,C6,C7 & 0.1$\mu$F & C050-024X044    & ceramic disc capacitor  &  399-9870-1-ND \\
$\square$ C3        & 10$\mu$F    & E2,5-7          & polarized capacitor  & P15799CT-ND  \\
$\square$ D1,D2     & BAT43       & DO35-7          & Schottky diode, 0.45V fwd, 30V, 200mA  &  497-2492-1-ND \\
$\square$ DCJACK    & PJ102A      & PJ-102A         & DC jack, 2.0mm center pin, 5.5mm plug  & CP-102A-ND \\
$\square$ IC1, IC2  & LM555N      & DIL08           & 555 Timer IC  & 296-9684-5-ND \\
$\square$ SOCKET1,2 & A 08-LC-TT  & DIL08           & 8 pin DIP IC socket  & AE9986-ND \\
$\square$ JP1       & M01PTH      & 1X01            & 1-pin header to ground  & S1011EC-40-ND \\
$\square$ LED1      & 859-LTL2R3KRD-EM & 5mm, 2.54mm spacing & red LED, 2mA, 1.8V fwd  & 160-1853-ND \\
$\square$ LINE      & SJ-3523-SMT & SJ352 Audio Jack & CUI inc Stereo Audio SMT jack, 3.5mm & CP-3523SJCT-ND \\
$\square$ MOD       & 0.1\texttt{"} header          & 1X03 & 3 pin header for mods  & (see above) \\
$\square$ R1,R6,R7  & 220R        & 0207/7          & through-hole resistor  & CF18JT220RCT-ND \\
$\square$ R2        & 1K          & 0207/7          & through-hole resistor  & S1KQCT-ND  \\
$\square$ R3        & 250K        & CTS UM296RE pot & Frequency potentiometer  &  CT2269-ND   \\
$\square$ R4        & 500K        & CTS UM296RE pot & Pulse-width potentiometer  &  CT2270-ND  \\
$\square$ R5        & 5K          & CTS UM296RE pot & Volume potentiometer  &  CT2264-ND \\
$\square$ SWITCH    & 108-1MD3T1B1M2QE-EVX & ---       & Mountain Switch DPDT center-off switch & (only at Mouser)  \\
$\square$ TOUCHPAD1,2 & 0.1\texttt{"} header & JP1, JP2 & optional touch pad connection  & (see above)\\[\sep]
\hline\\[\negsep]

\end{tabular}
\end{footnotesize}

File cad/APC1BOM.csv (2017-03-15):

Part | Value | Device | Package | Description | MOUSER | SPICEMODEL | SPICEPREFIX | SPICETYPE | VALUE
BAT1 | 6-15V | BH-9VPC | BH9VPC | These specs, though the battery holder is imprinted with BH-9VPC, match the specs of part number 12BH611-GR.
BINAURAL | BINAURAL | JP1E | JP1 | JUMPER
C1 | 0.01uF | C-EU050-024X044 | C050-024X044 | CAPACITOR, European symbol
C2 | 0.1uF | C-EU050-024X044 | C050-024X044 | CAPACITOR, European symbol
C3 | 10uF | CPOL-USE2.5-7 | E2,5-7 | POLARIZED CAPACITOR, American symbol
C4 | 0.1uF | C-EU050-024X044 | C050-024X044 | CAPACITOR, European symbol
C5 | 0.01uF | C-EU050-024X044 | C050-024X044 | CAPACITOR, European symbol
C6 | 0.1uF | C-EU050-024X044 | C050-024X044 | CAPACITOR, European symbol
C7 | 0.1uF | C-EU050-024X044 | C050-024X044 | CAPACITOR, European symbol
C8 | 0.01uF | CPOL-USE2.5-7 | E2,5-7 | POLARIZED CAPACITOR, American symbol
D1 | BAT43 | SCHOTTKY-DIODEDO35-7 | DO35-7 | Schottky Diode
D2 | BAT43 | SCHOTTKY-DIODEDO35-7 | DO35-7 | Schottky Diode
DCJACK | PJ102A | PJ102A | PJ-102A
IC1 | LM555N | LM555N | DIL08 | TIMER
IC2 | LM555N | LM555N | DIL08 | TIMER
JP1 | M01PTH | M01PTH | 1X01 | Header 1
LED1 | RED | LED_ELD260 | LED_LD260 | LED |  | NONE | D | diode
LINE | SJ-3523-SMT | SJ-3523-SMT | SJ352_AUDIOJACK | CUI inc Stereo Audio SMT jack, 3.5mm
MOD | 0.1 Jumper" | M03LOCK | 1X03_LOCK | Header 3
R2 | 1K | R-US_0207/10 | 0207/10 | RESISTOR, American symbol
R3 |  | CTS_UM296RE_SERIES_POTENTIOMETERUM296RE | UM296RE_POTENTIOMETER | CTS UM296 RE rotary potentiometer / rheostat / varistor / variable resistor.
R4 |  | CTS_UM296RE_SERIES_POTENTIOMETERUM296RE | UM296RE_POTENTIOMETER | CTS UM296 RE rotary potentiometer / rheostat / varistor / variable resistor.
R5 |  | CTS_UM296RE_SERIES_POTENTIOMETERUM296RE | UM296RE_POTENTIOMETER | CTS UM296 RE rotary potentiometer / rheostat / varistor / variable resistor.
R6 | 220R | R-US_0207/10 | 0207/10 | RESISTOR, American symbol
SWITCH | MS108-1MD3T1B1M2QE-EVX | MS108-1MD3T1B1M2QE-EVX | MS108-1MD3T1B1M2QE-EVX | Mountain Switch Toggle DPDT model 108-1MD3T1B1M2QE-EVX | 108-1MD3T1B1M2QE-EVX
TOUCHPAD1 | TOUCHPAD | JP1E | JP1 | JUMPER
TOUCHPAD2 | TOUCHPAD | JP1E | JP1 | JUMPER

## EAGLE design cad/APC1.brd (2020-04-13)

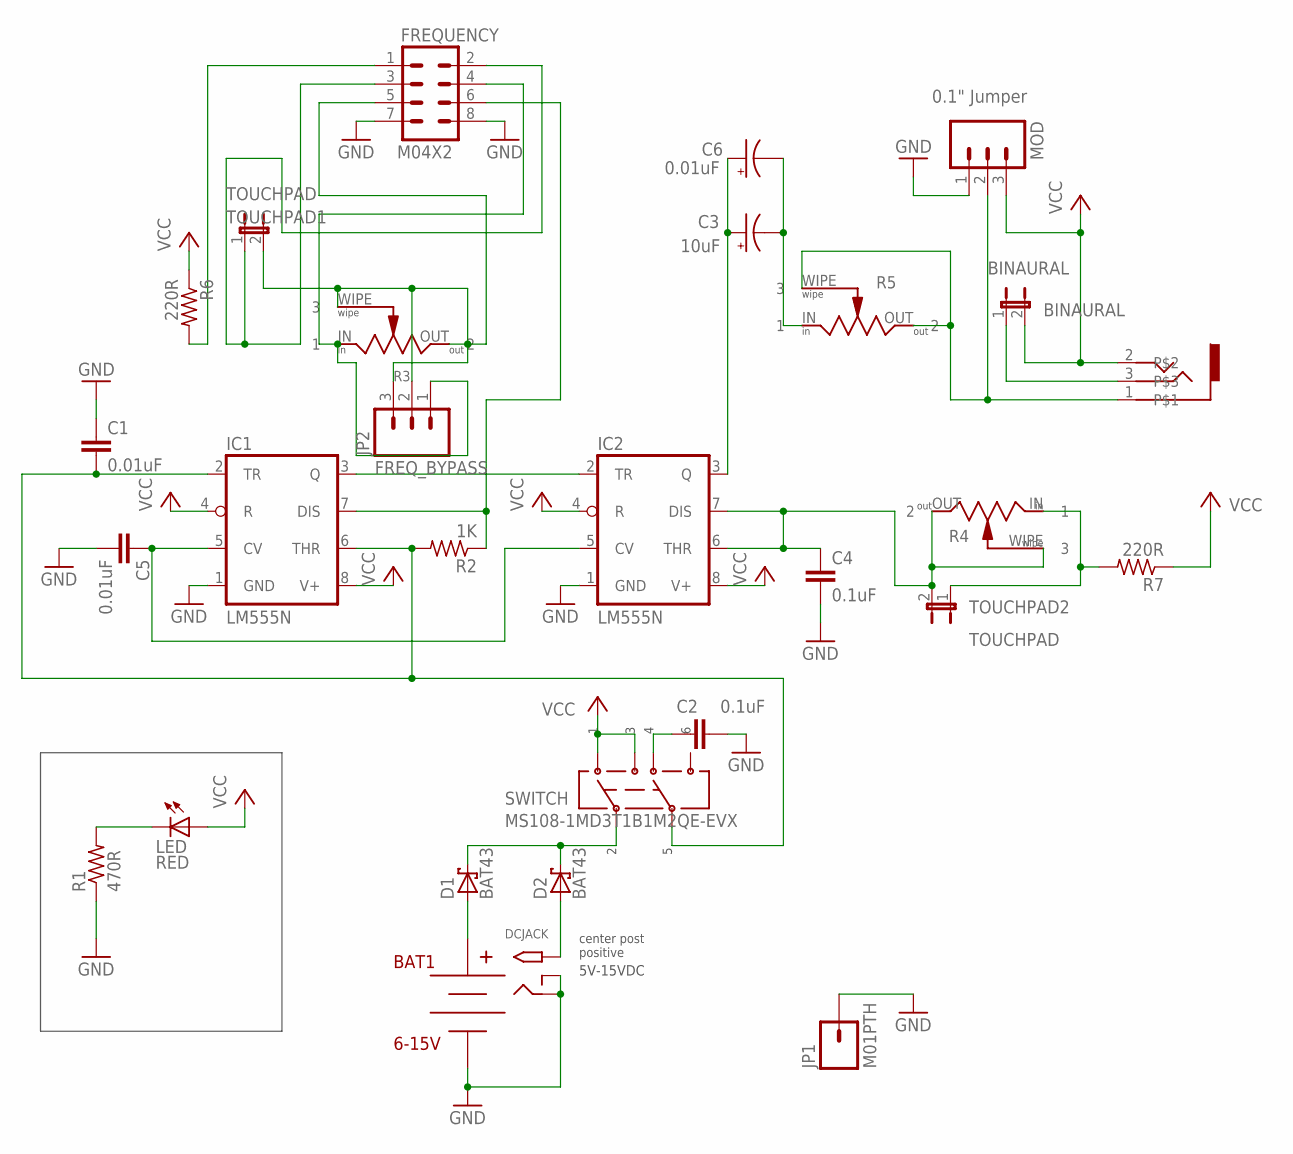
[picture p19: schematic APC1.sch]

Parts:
BAT1: 6-15V; BH9VPC
BINAURAL: BINAURAL; JP1
C1, C5: 0.01uF; C050-024X044
C2, C4: 0.1uF; C050-024X044
C3: 10uF; E2,5-7
C6: 0.01uF; E2,5-7
D1, D2: BAT43; DO35-7
DCJACK: PJ102A; PJ-102A
FREQUENCY: M04X2; 2X4
IC1, IC2: LM555N; DIL08
JP1: M01PTH; 1X01
JP2: FREQ_BYPASS; 1X03_SMD_RA_MALE
LED: RED; LED_LD260
LINE: SJ-3523-SMT; SJ352_AUDIOJACK
MOD: 0.1" Jumper; 1X03_LOCK
R1: 470R; 0207/7
R2: 1K; 0207/7
R3, R4, R5: CTS_UM296RE_SERIES_POTENTIOMETERUM296RE; UM296RE_POTENTIOMETER
R6, R7: 220R; 0207/7
SWITCH: MS108-1MD3T1B1M2QE-EVX
TOUCHPAD1, TOUCHPAD2: TOUCHPAD; JP1

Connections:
GND: BAT1.P$1 (V-), C1.1, C2.2, C4.2, C5.2, DCJACK.P$2 (RING), DCJACK.P$3 (RING_SW), FREQUENCY.7, FREQUENCY.8, IC1.1 (GND), IC2.1 (GND), JP1.1, MOD.1, R1.1
unnamed: FREQUENCY.5, JP2.2, JP2.3, R3.OUT (2), R3.WIPE (3), TOUCHPAD1.2
unnamed: C2.1, SWITCH.P$4 (4)
unnamed: C4.1, IC2.6 (THR), IC2.7 (DIS), R4.OUT (2), R4.WIPE (3), TOUCHPAD2.2
unnamed: IC1.3 (Q), IC2.2 (TR)
unnamed: C5.1, IC1.5 (CV), IC2.5 (CV)
unnamed: LED.K (C), R1.2
unnamed: BINAURAL.1, LINE.3
unnamed: C3.+, C6.+, IC2.3 (Q)
unnamed: C1.2, IC1.2 (TR), IC1.6 (THR), R2.2, SWITCH.P$5 (5)
unnamed: BAT1.P$2 (V+), D1.A
unnamed: D2.A, DCJACK.P$1 (TIP)
unnamed: LINE.1, MOD.2, R5.OUT (2), R5.WIPE (3)
unnamed: R4.IN (1), R7.2, TOUCHPAD2.1
unnamed: FREQUENCY.2, FREQUENCY.3, TOUCHPAD1.1
unnamed: C3.-, C6.-, R5.IN (1)
unnamed: FREQUENCY.1, R6.2
unnamed: FREQUENCY.4, JP2.1, R3.IN (1)
unnamed: FREQUENCY.6, IC1.7 (DIS), R2.1
VCC: BINAURAL.2, IC1.4 (R), IC1.8 (V+), IC2.4 (R), IC2.8 (V+), LED.A, LINE.2, MOD.3, R6.1, R7.1, SWITCH.P$1 (1), SWITCH.P$3 (3)
VIN: D1.C, D2.C, SWITCH.P$2 (2)

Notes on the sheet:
5V-15VDC
center post positive

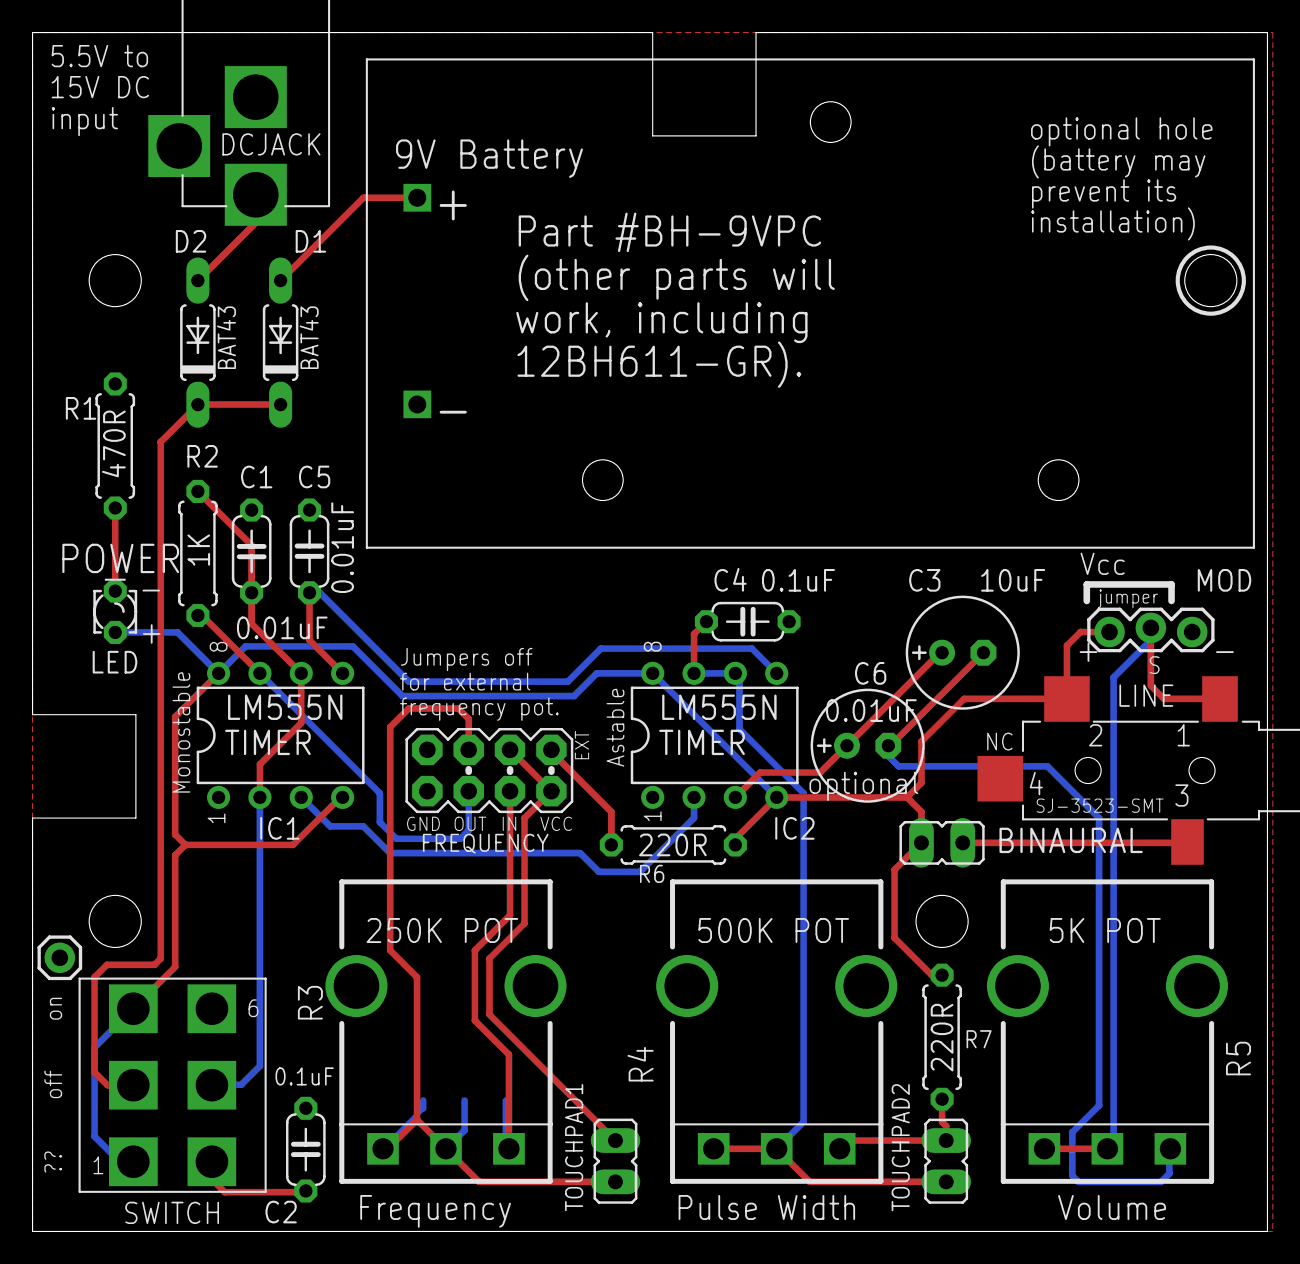
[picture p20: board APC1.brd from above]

Board: 2 copper layers, 75.9 x 73.7 mm, 29 parts (1 on the bottom side), 21 nets.

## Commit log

2017-03-15 Initial commit. Creating repository.
    [APC1.GBL, APC1.GBO, APC1.GBS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]
2017-03-21 Fixed wiring on pots; more careful routing I had changed the schematic for two pots incorrectly, volume and pulse width. Added two current-limiting resistors for the freq. and pulse width pots. Spent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
    [APC1.brd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]
2017-09-23 Cleanup and a few additions. Added PCB photo.
    [APC1.brd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]
2017-09-25 reformatting BOM and adding part ordering info
2020-04-13 v.1.2 of board. Documentation changes / improvements.
    [APC1.brd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]

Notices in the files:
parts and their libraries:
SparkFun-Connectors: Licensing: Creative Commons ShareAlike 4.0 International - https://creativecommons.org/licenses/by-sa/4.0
